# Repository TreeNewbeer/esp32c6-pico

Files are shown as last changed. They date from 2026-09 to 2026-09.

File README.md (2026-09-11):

# ESP32-C6 Pico · Rev A

2026-09-11 第一版 PCB 提交快照：保留用户在居中后对 R19、R15、局部短线及图形的继续调整；R19 / R15 当前坐标为 (115.70, 120.40) / (115.70, 122.36) mm。已重新填铜并同步贴装坐标、二维预览和报告，**ERC 0、DRC 错误 0 / 丝印警告 1、未连接 0、一致性问题 0，QA 39/53**。见 [当前提交记录](output/first-pcb-revision.json)。以下居中对比及旧 3D 图保留为历史记录。

2026-09-10 最新 PCB 微调：以用户已基本完成的第一版 layout 为输入，USB 向右 1.00 mm、两颗按键各向右 0.50 mm，均对齐板框中心 X=110.00 mm；按键间距及纵向位置不变，RST / BOOT 文字跟随移动，D2 位号丝印隐藏。为避让孔位及器件庭院，D4 向右 0.20 mm / 向下 0.10 mm、R15 向右 0.50 mm，局部修整短线；其余器件位置及板框、射频、晶振、禁布区不变。原理图和电路网络未改动，过孔仍为 89 个。重新填铜后 **ERC 0、DRC 错误 0、未连接 0、一致性 0**，保留输入已有的 1 项板头丝印警告；**QA 39/53，无新增失败项**。贴装坐标、二维预览和当前原理图导出的网表已更新，旧 3D 图为历史记录。见 [修改记录](output/usb-buttons-centered.json) 与 [前后对比](output/usb-buttons-centered-comparison.png)；以下先前轮次的数据仅作历史参考。

2026-09-10 最新（仅原理图）：RGB 控制已由 GPIO21 切回 **GPIO8（U1.14，与 J2.7 共用）**，GPIO21（U1.34）标记不连接。已按用户确认对齐官方 DevKitC-1 v1.4：**R9 = 3.3 kΩ 将 GPIO8 上拉到 3.3 V，R19 = 10 kΩ 将二极管阳极侧数据节点上拉到 5 V，R15 = 0 Ω 串联接入 DIN**。保留两颗上拉，D6 阴极朝 GPIO8；R9 / R15 的阻值、BOM 和检查条件均已同步。ERC 0，主控外围实线检查全部通过。PCB、布局和贴装坐标未修改，尚未同步这次 GPIO8 变更；既有 DRC / QA 报告不是新原理图的一致性验证。最新网表、BOM 和两页预览已更新；设计清单同时修正输入原理图已有的 J3 脚序及 D2 封装字段偏差，未改动这些电路。见 [GPIO8 原理图记录](output/rgb-gpio8-schematic.json) 与 [RGB 局部预览](output/schematic/rgb-gpio8.png)。

以下布局轮次和检查数字为历史记录；当前原理图与 PCB 的同步状态以上述说明为准。

当前 PCB 为 **18.0 × 29.0 mm、四层、标称 0.8 mm**，使用 ESP32-C6 QFN40、4 MB 外置 Flash、横向陶瓷天线与原生 USB Serial/JTAG。已按最新原理图移除 USB 的 R12、R13、C27、C28 并完成 USB 直连布线；RGB 灯改用二极管加 5 V 上拉驱动，不再使用电平转换芯片。

2026-09-10 此前 RGB 驱动同步：**按官方 ESP32-C6-DevKitC-1 v1.4 的方式，用 D6（1N4148WS / SOD-323）+ R19（10 kΩ 上拉到 USB 5 V）替换 SN74LV1T125 电平转换器**，删除 U4、其去耦 C26 和 GPIO21 下拉 R16；R15 = 330 Ω 移到 D2 的 DIN 焊盘旁，原来绕过 D2 的数据绕线一并删除。庭院净省约 10 mm²，背面原缓冲器口袋基本腾空，少一个 IC 料号。电平按二极管压降核算（高电平约 3.9 V > 0.7 × VDD，低电平约 0.7 V < 0.3 × VDD，10 kΩ 上拉上升沿约 105 ns），**尚未上电或用示波器实测**。范围、基线对比与哈希见 [RGB 二极管驱动记录](output/rgb-diode-drive.json)，局部对比见 [改动前后对比图](output/rgb-diode-comparison.png)。

2026-09-10 此前 USB 同步：**删除 R12 / R13（22 Ω 串阻）和 C27 / C28（选装电容）**，U1.18 / U1.19 直接连接 USB_D− / USB_D+；保留 USB-C、CC 下拉及 D4 静电保护。清除两条电容支路及其过孔，简化主控附近走线；保持 0.15 mm 线宽、每根数据线两次换层，不增加蛇形补偿。

当前 **59 个器件位、55 个默认装配；ERC 0、原理图一致性 0**。PCB 仍处在重排右排针（J3）的过程中，**DRC 5 项违规、9 项未连接、QA 45/53**：既有的 MCU 7/9 个中心地孔两项检查、匹配网络共轴、天线/晶振间距，加上尚未连上的 7 条 J3 网络、3 个未盖油过孔和 R14 旁一处 +3V3 间距。这些项与 RGB 改动前的同一工程基线（DRC 5、未连接 9、QA 44/52）逐项一致，本轮没有新增违规，但**投板前必须先完成 J3 布线并清零**。除本轮 RGB 三件外，其余器件的位置、角度、安装面和封装不变；BOM、坐标、原理图和 PCB 预览已更新，详见 [RGB 二极管驱动记录](output/rgb-diode-drive.json) 与 [USB 同步记录](output/usb-layout-sync.json)。尚未进行实板 USB、RGB 或射频验证。

以下引脚同步及布局调整记录为历史状态；当前器件数、USB 与 RGB 电路以上面两段为准。

2026-09-10 此前引脚同步：**J2 / J3 全部 24 个脚位已按用户修改的原理图更新，信号、电源和接地均已连通，包括 GPIO5（U1.11 → J2.4）**。左列从板头依次为 GPIO2–GPIO11、3V3、GND；右列为 GPIO1、GPIO0、GPIO15、TX、RX、GPIO18、GPIO19、GPIO20、GPIO22、GPIO23、5V、GND。背面功能丝印、设计清单、原理图预览及 PCB 预览已同步。

**全部 64 个器件的位置、角度、安装面、封装和装配状态均保持输入状态**；板框、logo、禁布区，以及 RF、晶振、USB、Flash 等非排针网络的原有铜线几何保持不变。重排排针支路，同时接回输入板已断开的 C8/C9/C10 3V3 支路，恢复 64 个器件的原理图关联路径。为分隔的表层地铜补充四颗接地过孔，Y1.2 最近地孔距离改善为 0.65 mm；另将一颗原有 VBUS_USB 过孔明确设置为双面盖油。过孔从本次实际输入的 122 颗变为 130 颗。

当前 **ERC 0、DRC 违规 0、未连接 0、原理图一致性 0；独立 QA 48/52**。没有新增失败项；保留四项既有失败：MCU 中心地孔仍为 7/9（两项检查）、天线匹配器件共轴及天线/晶振 8.5 mm 间距目标。最新报告与输入基线见 [引脚同步记录](output/pin-layout-sync.json)；尚未进行实板或射频验证。以下收窄记录属于本轮之前的历史状态，旧脚位和 GPIO5 待连状态以本段及下方接口表为准。

2026-09-10 左侧收窄：板框现为 **18.0 × 29.0 mm**，左板边与 J2 同步右移 **2.00 mm（四个 0.50 mm 步长）**，面积由 580 降至 522 mm²，减少 10%。J2 / J3 中心 X 为 102.25 / 117.75 mm，列中心距 15.50 mm；针距仍为 2.00 mm，焊盘铜到两侧板边仍各 0.575 mm。为避让左排针，仅另调整背面的 C8、C28、R8，其他 60 个器件保持位置、安装面和封装，L2、RF/晶振走线及 USB 数据主干保持不动。J2 第 4 / 5 脚改为 GPIO2 / GPIO1，原理图、设计清单及背面丝印已同步。

历史收窄轮次的待连状态（本轮已完成）：**当时按用户要求保留 GPIO5，U1.11 → J2.8。** U1 焊盘中心为 (106.5625, 115.20) mm，J2 焊盘中心为 (102.25, 128.00) mm；该网络已清除未完成的线头，打开 KiCad 后可直接按飞线补接，信号宽度为 0.15 mm，In1.Cu 继续留作 GND。当前 **ERC 0、DRC 违规 0、原理图一致性 0、未连接 1；QA 45/52**。QA 保留原有六项失败，新增的一项失败就是这条明确预留的连接，未放宽检查。总过孔由 125 减至 124。完成 GPIO5 后须重填铜并重新运行 DRC / QA；当前不是已全部布线的生产文件。范围、备份与端点见 [18 mm 收窄记录](output/width-18mm.json)。

2026-09-09 历史 L2 调整：**L2（2 nH、0402）移至 B.Cu**，从 (102.10, 113.00) mm 移到 (111.55, 112.65) mm，腾出正面左排针旁的原占位。其余 63 个器件、全部信号线、板框、禁布区和两个 logo 均保持输入状态；C11/C19/C20 保持正面。只调整 +3V3 / V3A 的局部连接，移除原输入过孔，新增一颗双面盖油的输出过孔，总数仍为 125。到 U1 两个供电脚的路径约 3.7–3.9 mm（含标称 0.8 mm 过孔贯穿长度）。填铜后 **DRC 0、未连接 0、一致性 0；QA 46/52**，较本次实际输入的 45/51 新增一项通过检查，原有六项失败不变。BOM 器件信息不变，装配坐标和正反面预览已同步；射频与供电表现尚未实测。该轮范围、备份和验证见 [L2 迁移记录](output/l2-back-migration.json)，后文各轮数字保留为历史记录。

2026-09-09 封装替换：**U3 改为 W25Q32JVSNIQ、150 mil SOIC-8（3.9 × 4.9 mm 本体）**；**D5 改为 at820_tiga 的 BAT760-7 / SOD-323**，保持防反灌方向。U3 向左 0.20 mm、向板头 0.10 mm，C6 向右 0.10 mm，D5 中心不动；其余 62 个器件的封装、位置和安装面不变。板框、射频、晶振和 USB 数据线几何保持不变。SOIC 引脚焊盘较长，占位略增；D5 庭院占位约减少 39%，本轮没有缩小板框。

本轮已重新导出网表、ERC、填铜、DRC 和独立 QA：**ERC 0、DRC 0、未连接 0、一致性 0；QA 45/51**，无新增失败项。修改前实际文件重新检查为 43/49，保留 MCU 接地孔数量、匹配网络共轴、天线/晶振间距、晶振接地孔距离、MCU 散热孔清单及一颗普通过孔未显式双面盖油六项既有失败。SOIC-8 没有中心焊盘，工艺目标改为仅 U1 的 9 孔，当前实有 7 孔；没有降低 U1 的要求。具体变更、哈希与基线见 [封装替换记录](output/package-changes.json)。

**F1 已按用户要求删除**：原理图和 PCB 均移除 1206 自恢复保险丝，USB 的 `VBUS_USB` 直接连接 D5 阳极，取消 `VBUS_FUSED` 网络。移除绕到板尾 F1 的走线，保留 D5 防反灌；其余 64 个器件的位置、安装面和封装不变。BOM、装配坐标及预览已同步，默认装配由 59 个减为 58 个。删除后的 ERC、DRC、未连接和原理图一致性均为 0；QA 仍为 45/51，六项既有失败不变。删除 F1 时的检查结果为历史记录，最新结果见上方引脚同步记录。

2026-09-09 历史原理图复核：已对照 `docs/` 的 WROOM-1 / WROOM-1U 模组图，将晶振串联器件 **L4 = 24 nH 更正为 R18 = 0 Ω、0402 电阻**，对应模组图的 R4；原理图符号、PCB 封装、BOM 和检查条件均已同步。另记录 VDDA3P3、VDDA1/VDDA2 的本地去耦差异。重新填铜后，ERC 0 项、原理图一致性 0 项、未连接 0 项；DRC 仍有原有 2 项，独立 QA **43/48 通过**。详细依据与风险见 [外围电路复核](docs/ESP32_C6_SCHEMATIC_REVIEW.md)。下文跳过 QA 的描述属于此前布局轮次。

天线本体在板头右侧横向放置，末端铜箔向左展开、保持开路；板头全层不铺铜区域为 **18.0 × 3.8 mm**。AE1 馈电焊盘与 R6 对齐，正面馈线直接向下连接，不再从匹配网络折返向左。Codex 图标移至左侧；Flash U3、USB TVS D4 和排针位于背面，两颗按键位于正面。

六颗 Flash 串联电阻 R17、R1–R5 已改为 0402，在背面排成一行，中心间距 1.20 mm。Flash U3 与 TVS D4 各向 USB 方向移动 0.80 mm，为焊盘外过孔和这排电阻留出空间；板框不变。C7 在主控 VDD_SPI 扇出旁的正面，C13 位于 3.3V 供电脚附近，保留短去耦连接。RGB 驱动改为二极管电平转换后，D6 占用背面原缓冲器位置，R19、R15 移到 D2 右侧的正面空位，DIN 与数据节点的绕行走线随之删除。排针功能标注统一保留在背面，正面左侧的重复标注已清除。

2026-09-09 历史板宽调整：在天线右移后的 20.5 × 29 mm 版上，将左右板边各收窄 **0.25 mm**，当前板框为 **20 × 29 mm**，面积从 594.5 mm² 降至 **580.0 mm²（减少约 2.44%）**。两列排针位置与 18.10 mm 列间距保持不动，焊盘外缘距两侧板边均为 **0.275 mm**，满足当前 0.25 mm 规则。器件、过孔及走线几何保持输入版本。贴装坐标原点同步更新到新板框左下角 (99.00, 137.50) mm。

2026-09-09 排针内移：板框保持 **20 × 29 mm**，J2 向右、J3 向左各移动 **0.30 mm**，两列中心距由 18.10 mm 改为 **17.50 mm**。J2 / J3 中心 X 分别为 100.25 / 117.75 mm，针距 2.00 mm、脚号与网络顺序不变。焊盘铜外缘距左右侧边各 **0.575 mm**；按封装标称 2.00 mm 宽塑料座计算，本体距侧边各 **0.25 mm**。背面引脚标注及相关局部走线已同步调整，最新预览与装配坐标位于 `output/`。

重新填铜后，**DRC 0 项、未连接 0 项、原理图一致性 0 项**；独立 QA **44/49 通过**，新增的排针边距检查通过，其余五项失败均在修改前存在。旧 `output/qa.json` 的 PCB 哈希与输入文件不符，因此已对原始备份重新建立基线（43/48），未沿用旧报告中的两项孔距违规。当前剩余项为 MCU 接地孔数量、天线匹配器件共轴、天线/晶振间距、晶振接地过孔距离及 11 个散热孔清单。范围与基线对照见 [排针内移检查记录](output/headers-inward.json)。

天线与晶振名义本体边缘最近距离约 **5.070 mm**，低于历史 8.5 mm 项目几何目标；与本次输入 PCB 一致。该历史门槛保持不变，当前独立 QA 据此报告失败。射频和晶振信号仍在正面且不换层，晶振规则区保留；3.8 mm 净空及右侧天线布局尚需实板射频验证。

正面天线旁原 `2.4 GHz` / `NO COPPER` 丝印替换为 **Codex 图标**；背面加入用户个人 logo 的单色人物图形，并将 `REV A` 移到旁边。两个 logo 都是可编辑丝印图形组，背面按正常观看方向镜像放置。原图、SVG、来源和尺寸记录见 [docs/logo/README.md](docs/logo/README.md)。

直接用 KiCad 10 打开 `esp32-c6-pico.kicad_pro`。如编辑器仍显示修改前的内容，请关闭旧窗口并重新打开磁盘文件，避免旧窗口覆盖新文件。

当前封装约定：**射频匹配的 6 个电阻/电容保持 0201，其余全部 35 个电阻/电容统一 0402**，包括 C19、C20、C23 等大容量电源电容及 Flash 串阻。容量、阻值、网络和 DNP 状态保持不变。大容量电源电容保留最低 10V 额定耐压要求，实际料号与偏压下的有效容量仍需核对。变更清单见 [POWER_PASSIVES.md](POWER_PASSIVES.md) 和 [全部阻容封装表](output/passive-packages.csv)。

主原理图已把 ESP32-C6 的供电去耦、上电复位、BOOT、晶振、Flash、USB 直连引出、UART 与 RGB 驱动沿芯片引脚用实线连接。电源输入、USB 接口与排针位于第二页。USB 数据引脚已与第二页的同名数据网络直接连接。

此前尝试了 **18 × 30 mm**：目标尺寸的器件摆放可以容纳，但布线候选仍有 18 处未连接，该轮主工程保留了 20.5 × 32.5 mm，后续从板头收短到 32.0 mm。此前候选、剩余问题和原始检查结果见 [SHRINK_TRIAL.md](SHRINK_TRIAL.md)。

## 已完成的电路

- USB-C 正反插数据连接、CC1/CC2 独立 5.1 kΩ 下拉、USBLC6-2SC6 静电保护；数据线直接连接主控，已删除 22 Ω 串联电阻及选装 EMI 电容。
- AP2112K-3.3 稳压、输入保护、肖特基防反灌、主电源及各供电脚的去耦；RF 电源使用独立 LC 滤波。
- CHIP_EN 的 10 kΩ / 1 µF 上电延时，RESET、BOOT 按键，GPIO8/9 上拉与 UART0 备用下载接口。
- W25Q32JVSNIQ、SOIC-8 150 mil 外置 Flash，真正接通 VDD_SPI；40 MHz / 8 pF 晶振，两个外壳脚接地，并保留负载调试与 R18 = 0 Ω 串联电阻。
- 芯片端 CLCCL 射频网络、天线端 π 网络、低电容 ESD 选装位，以及陶瓷天线开路端调谐铜箔。
- WS2812B-2020 RGB 灯：原理图改由 GPIO8 经 D6（1N4148WS）与 R19（10 kΩ 上拉到 USB 5 V）驱动，R9 = 3.3 kΩ 保留 GPIO8 的 3.3 V 上拉，R15 = 0 Ω 接入 DIN，控制引脚和三个电阻值已按官方 v1.4 对齐；PCB 待用户同步。

## 检查与交付文件

当前原理图 ERC 0、实线检查通过，见 `output/rgb-gpio8-schematic.json`。PCB 尚未同步本次 GPIO8 变更；`output/drc-final.json` 和 `output/qa.json` 保留此前布局结果，下文各日期记录保留当时状态。

2026-09-09 历史排针内移轮次使用 KiCad 10.0.6 重新填铜并检查：**DRC 0 项、未连接 0 项、原理图一致性 0 项；独立 QA 44/49 通过，无新增失败项**。本轮未修改原理图，既有 ERC 报告为 0 项。当前报告为 `output/drc-final.json`、`output/qa.json` 和 `output/headers-inward.json`；`output/layout-20x29mm.json` 及此前两项孔距违规的记录属于历史轮次。

原先 65 项一致性报错来自 PCB 器件字段缺失。现已按原理图为 65 个器件同步 141 处字段，包括 MPN、AssemblyNote 和 Datasheet；新增字段隐藏显示，保留封装库自带的额外字段。原理图、网络连接、封装、器件值和 DNP 状态保持不变。已重新填铜，并在重新加载磁盘 PCB 后启用 `--schematic-parity` 验证为 0 项；QA 新增逐字段比较与一致性报告检查，后续 DRC 命令也必须带此参数。

USB 保持简洁路径，没有加入蛇形等长补偿。两根线在按键上方换到底层，经过靠近连接器的 TVS，再换回正面连接 USB-C 焊盘。接受自然扇出带来的少量长度差；QA 长度统计区分铜层，并计入标称过孔贯穿长度。

全板信号走线统一为 **0.15 mm**（含 USB、射频、晶振及芯片扇出），非 GND 电源走线统一为 **0.20 mm**；GND 保留原有线宽。`Power` 网络类覆盖 `+3V3`、`+5V`、`V3A`、`VBUS_USB`、`VDD_SPI`，其他信号使用 `Default`。自定义规则同时限制最小和最大线宽，独立 QA 核对每段走线与实际网络类；相关局部路径已按新宽度调整。线宽统一不代表阻抗或载流能力已经实测达标。

外围焊盘内的过孔已改为焊盘外短线扇出，并检查正反面的阻焊开窗；孔边间距至少 0.10 mm。当前仅允许 U1 中心接地焊盘的 9 个填孔盖铜过孔，实际清单为 7 个；SOIC-8 U3 无中心焊盘。为腾出局部扇出空间，调整了 C7、C11、R2、R3、R7 的位置；同批调整的 C27、R16 已在后续 USB 与 RGB 简化中删除。

| 文件 | 用途 |
| --- | --- |
| `esp32-c6-pico.kicad_sch` / `power-io.kicad_sch` | 两张可编辑原理图 |
| `esp32-c6-pico.kicad_pcb` | 已布线 PCB，含叠层和禁布区 |
| `esp32-c6-pico.kicad_dru` | 固定线宽、焊盘孔距与晶振下方的非接地过孔禁布规则 |
| `output/pcb-front.svg` / `pcb-back.svg` | 正反面布线预览 |
| `output/rgb-diode-drive.json` | RGB 二极管电平转换的改动范围、基线对比与验证 |
| `output/rgb-diode-comparison.png` / `.svg` | RGB 驱动改动前后的正反面局部对比 |
| `output/pin-layout-sync.json` | 最新排针引脚、完整布线、位置保护、输入基线及验证 |
| `output/width-18mm.json` | 历史 18 mm 收窄、当时 GPIO 换序与待连线记录 |
| `output/l2-back-migration.json` | L2 背面迁移范围、备份、连通性及检查基线 |
| `output/package-changes.json` | 历史封装替换范围、尺寸、网表与检查基线 |
| `output/headers-inward.json` | 历史排针内移的尺寸、修改范围及检查基线 |
| `output/width-20mm-comparison.png` / `.svg` | 历史 20.5 → 20.0 mm 板宽对比 |
| `output/antenna-right-29mm-comparison.png` / `.svg` | 历史 28 → 29 mm 与天线右移对比 |
| `output/antenna-28mm-comparison.png` / `.svg` | 历史 32 → 28 mm 压缩对比 |
| `output/antenna-layout-comparison.png` / `.svg` | 此前天线末端铜箔调整的历史对比 |
| `output/usb-routing-comparison.png` / `.svg` | 此前删除 USB 蛇形的历史局部对比 |
| `output/layout-repack-comparison.png` / `.svg` | 此前换面布局及缩短板框的历史对比 |
| `output/crystal-isolation-comparison.png` / `.svg` | 此前天线前移并加长板框的历史对比 |
| `output/crystal-down-headers-comparison.png` / `.svg` | 此前晶振下移、排针换面与尺寸调整对比 |
| `output/board-3d-top.png` / `board-3d-bottom.png` | 含最新 logo 的正反面 3D 布局预览 |
| `docs/logo/` | 个人原图、两面丝印 SVG、图形来源和放置参数 |
| `output/assembly-front.svg` / `assembly-back.svg` | 带位号的装配视图 |
| `POWER_PASSIVES.md` / `output/power-passives.csv` | 当前 0402 约定、封装变更记录和选料说明 |
| `output/passive-packages.csv` | 全部 40 个电阻/电容及累计 12 个封装变化记录 |
| `output/bom.csv` | BOM；`Populate=NO` 表示不装 |
| `output/placement.csv` | 双面贴装坐标，已排除 DNP；坐标原点为板左下角 |
| `output/via-in-pad.csv` | 当前 7 个 MCU 散热焊盘内孔，尚未满足 9 孔目标；须填孔盖铜 |
| `FABRICATION.md` | 必须确认的工艺、阻抗与样板验证项目 |

板上共 59 个器件位，默认装配 55 个。默认不装 D1、L3、C17、C18。3D 图为布局示意，部分标准库封装缺少 3D 模型；器件是否装配以 BOM 和二维装配图为准。

## 接口与下载

**从正面看**，USB 朝下、天线朝上时，J2 在左、J3 在右，两列 1 脚均靠近天线；从背面观察时左右对调，编号不倒序。排针塑料座和长针在背面，正面为焊接端。针距为 **2.00 mm**，两列中心距为 **15.50 mm**；这些尺寸不能按 2.54 mm 面包板间距处理。

| 脚号 | J2（左列） | J3（右列） |
| --- | --- | --- |
| 1 | GPIO2 | GPIO1 |
| 2 | GPIO3 | GPIO0 |
| 3 | GPIO4 | GPIO15 |
| 4 | GPIO5 | UART0 TX / GPIO16 |
| 5 | GPIO6 | UART0 RX / GPIO17 |
| 6 | GPIO7 | GPIO18 |
| 7 | GPIO8 | GPIO19 |
| 8 | GPIO9 / BOOT | GPIO20 |
| 9 | GPIO10 | GPIO22 |
| 10 | GPIO11 | GPIO23 |
| 11 | 3V3 输出 | 5V 输出* |
| 12 | GND | GND |

*5V 引脚实际电压等于 USB 电压扣除 D5 压降，不是精密 5.00 V。USB 电源直接经 D5 给稳压器和 5V 引脚供电，板上不再设置自恢复保险丝；RGB 灯与其 10 kΩ 上拉接 USB 原始电源。3V3/5V 引脚按电源输出使用，不要在连接 USB 时再向这些引脚注入外部电源。所有 GPIO 为 3.3 V 逻辑。

USB 下载使用芯片内置 USB Serial/JTAG（GPIO12=D-，GPIO13=D+）。需要手动进入下载模式时：按住 BOOT，点按 RESET，再松开 BOOT。UART0 备用下载时，使用 3.3 V 电平的串口适配器，交叉连接 TX/RX 并共地。GPIO4、5、8、9、15 是启动配置脚，外接电路不能在复位时强制成错误电平。

## 设计边界

这是一版用于验证的样板设计，尚未进行上电、测温或射频实测。横向天线、轴向开路端铜箔、18.0 × 3.8 mm 净空和缩短后的地平面均属于本工程的样板选择；3.8 mm 不是厂商保证的最小净空，原参考板的增益、带宽和方向图不能直接套用。匹配、效率和通信表现需在实际板卡及外壳中验证。

射频匹配、晶振负载与名义阻抗均需结合实际叠层、装配和外壳确认。U1 的中心散热焊盘内孔须填孔盖铜，当前 7 孔尚未满足 9 孔目标，普通盖油不能替代；具体工艺与实板验证要求见 `FABRICATION.md`。

`tools/` 保留了设计过程与验证脚本。`verify_design.py` 可重跑网络与规则核对；布局生成和布线脚本会重建或修改 PCB，不能当成对最终布线无损的更新命令。

## 依据

- [Espressif ESP32-C6 原理图设计指南](https://docs.espressif.com/projects/esp-hardware-design-guidelines/zh_CN/latest/esp32c6/schematic-checklist.html)：供电、启动配置、晶振、USB 与射频匹配。
- [Espressif ESP32-C6 PCB 布局指南](https://docs.espressif.com/projects/esp-hardware-design-guidelines/zh_CN/latest/esp32c6/pcb-layout-design.html)：接地参考层、芯片底部接地、射频与时钟路径。
- 工程内 `docs/C127611_CAA3DCCF3A021118096CAD99FC50242A.pdf`，Walsin `ASC_RFANT5220110A0T_V13` 第 3–4 页：天线焊盘、开路端铜箔与测试板几何。
- [Eaton E9X 数据手册](https://www.eaton.com/content/dam/eaton/products/electronic-components/resources/data-sheet/eaton-e9x-crystal-resonator-mhz-data-sheet-elx1389-en.pdf)：Y1 的频率、负载、电气规格与引脚。
- [Diodes 1N4148WS 数据手册](https://www.diodes.com/assets/Datasheets/1N4148WS_BAV16WS.pdf)：RGB 数据电平转换二极管，SOD-323、VF ≤ 0.715 V @ 1 mA、CT ≤ 2 pF。
- 工程内 `docs/esp32-c6-devkitc-1-schematics_v1.4.pdf` 第 2 页：官方 RGB 驱动使用 D11（1N4148W）+ R29（10 kΩ 上拉到 VCC_5V）+ R17（0 Ω），本板据此改用同一结构。
- [Nexperia PESD5V0F1BL-Q 数据手册](https://assets.nexperia.com/documents/data-sheet/PESD5V0F1BL-Q.pdf)：低电容天线 ESD 选装器件。

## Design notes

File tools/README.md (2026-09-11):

# 设计过程脚本

2026-09-10 最新（仅原理图）：RGB 控制改为 GPIO8 / U1.14，与 J2.7 共用；U1.34 / GPIO21 标记不连接。实线检查与 RGB 拓扑检查同步到 GPIO8，重画模板也替换已删除的 U4 / C26 / R16 逻辑，保留二极管两侧的 R9 / R19。已按用户确认将 R9 改为 3.3 kΩ、R15 改为 0 Ω，R19 保持 10 kΩ；RGB 拓扑检查同时要求这三个官方阻值、R9 接 +3V3、J2.7 共用 GPIO8 及 GPIO21 已空置。新网表 ERC 0、实线检查全部通过；PCB 未改动，本轮未运行 PCB DRC / QA，旧报告不能作为新网表的一致性结论。设计清单和 BOM 按实际输入原理图修正已有的 J3 脚序、D2 封装字段偏差；没有重画或更改这些电路。见 [GPIO8 原理图记录](../output/rgb-gpio8-schematic.json)。

最终可编辑工程是上一级目录中的 KiCad 文件；`output/` 仅保留最终交付和检查结果。

`verify_design.py` 是核对入口：读取原理图导出的 `output/netlist.xml`、最终 PCB、ERC/DRC 报告，核对逐焊盘网络、封装、接地参考层、关键走线层和 USB 长度，并更新 QA/焊盘内孔清单。板框和天线净空尺寸从 PCB 几何读取，当前检查横放天线、18.0 × 29.0 mm 板框、18.0 × 3.8 mm 全层净空及末端铜箔的几何连续性。同时检查 Flash / TVS 在背面、两颗按键在正面，以及 USB 的换层数量和跨层路径连通性。晶振隔离检查还核对 8.5 mm 的项目本体间距目标、2.4 mm 的时钟引脚间距、各接地焊盘 1 mm 内的接地过孔，以及第二层填铜对晶振参考区和本体投影的完整覆盖。另检查排针在背面、编号从板头向下排列、2.00 mm 针距和 15.50 mm 列中心距，并核对排针标称 2.00 mm 宽塑料座及焊盘铜外缘距侧边分别至少 0.25 mm、0.575 mm。另核对两个 logo 图形组仅位于正确丝印层、旧天线文字已替换、图形距板边至少 0.25 mm。它不修改 PCB，也不验证射频性能。

2026-09-10 RGB 二极管驱动：按用户要求改用官方 ESP32-C6-DevKitC-1 v1.4 的驱动方式，删除 U4（SN74LV1T125）、去耦 C26 与下拉 R16，新增 D6（1N4148WS / SOD-323，阴极接 GPIO21）和 R19（10 kΩ 上拉到 VBUS_USB），R15 = 330 Ω 移到 D2 右侧并删除原来绕过 D2 的数据绕线。`verify_design.py` 新增一项 RGB 拓扑检查，封装数量核对改为 40 个 R/C，`component_sides` 记录 D6 / R19 / R15；`verify_schematic_wiring.py` 的实线清单同步为 D6、R19、R15。当前 **ERC 0、原理图一致性 0、DRC 5 项违规、9 项未连接、QA 45/53**；同一工程改动前（仅重新填铜）的基线为 DRC 5、未连接 9、QA 44/52，两者逐项一致，剩余项全部来自尚未完成的右排针（J3）布线，不是本次改动引入。详见 [RGB 二极管驱动记录](../output/rgb-diode-drive.json)。

2026-09-10 最新 USB 同步：删除 R12、R13、C27、C28，60 个器件位、56 个默认装配，**ERC / DRC / 未连接 / 一致性均为 0，QA 48/52**。四项既有失败不变。USB 路径检查直接核对 U1.18 / U1.19 到 USB-C 正反插数据焊盘的连接、旧器件和网络已移除；长度不再计入串阻焊盘间距。主页面实线检查追踪主控引脚到 USB 跨页标签的线段。`redraw_schematic.py` 的 USB 模板已同步为直连，本轮没有执行重画。详见 [USB 同步记录](../output/usb-layout-sync.json)。

2026-09-10 此前引脚同步：两列全部 24 个脚位按新原理图更新，GPIO5 已接到 J2.4；全部 64 个器件位置、角度与安装面不变。当前 **ERC 0、DRC 违规 0、一致性 0、未连接 0；QA 48/52**。保留四项既有失败（MCU 7/9 地孔的两项检查、匹配网络共轴、天线/晶振间距），没有新增失败项；晶振地孔距离和普通过孔显式双面盖油检查现已通过。网表、设计清单、器件原理图路径和预览已同步。详见 [引脚同步记录](../output/pin-layout-sync.json)。

2026-09-10 历史收窄为 18 × 29 mm，J2 第 4 / 5 脚改为 GPIO2 / GPIO1。用户授权保留 GPIO5（U1.11 → J2.8）供手动布线，当前 **ERC 0、DRC 违规 0、一致性 0、未连接 1；QA 45/52**。原有六项失败不变，额外失败为这一条待连线；`KiCad PCB has no unconnected items` 检查保持严格，不将授权的未完成连接当作通过。详见 [18 mm 记录](../output/width-18mm.json)。

`--board` 和 `--output-dir` 可用于隔离候选板的核对；对应目录需提供原理图网表及 ERC / DRC 报告。

2026-09-09 L2 迁移后，QA 增加背面安装、C11 保持正面及 V3A 到 U1.2/U1.3/C11/C19/C20 的跨层连通性检查。`rf_supply_filter` 记录输出路径和换层数量；长度按铜线中心线加标称过孔贯穿长度估算，不代表寄生参数或射频性能验证。本轮输入重新检查为 45/51，迁移后为 46/52，六项既有失败不变；DRC、未连接和原理图一致性均为 0。范围与备份见 [L2 迁移记录](../output/l2-back-migration.json)。

器件字段核对逐项比较 PCB 与网表中的 Value、MPN、AssemblyNote、Datasheet 等原理图实例字段，包括空值；封装库自带的额外字段保留。DRC 必须启用 `--schematic-parity`，其结果也纳入 QA。仅检查走线的 DRC 报告不能代替原理图一致性检查。

封装核对覆盖当前全部 40 个电阻、电容：射频匹配的 C2、C3、C16、C17、C18、R6 为 0201，其余 34 个为 0402。晶振串联器件按模组图由原 L4 更正为 R18 = 0 Ω；QA 同时核对其电阻符号、数值、装配状态及 U1.39 / Y1.1 / C4.1 的连接。定义与变更记录见 [POWER_PASSIVES.md](../POWER_PASSIVES.md)。

线宽核对覆盖全部走线和圆弧：信号固定 0.15 mm，非 GND 电源固定 0.20 mm，同时检查实际网络类及默认布线宽度。电源网络集合维护在 `build_pcb.py` 的 `POWER_NETS`，项目 `Power` 类与 `.kicad_dru` 应同步；GND 不参与固定线宽检查。QA 的 `track_width_policy` 保存各网络实际线宽和线段数量。

核对还包括正反面 SMD 阻焊开窗到孔边的 0.10 mm 间距，涵盖同网络及 DNP 焊盘；仅按固定位置允许 U1 的 9 个中心接地孔；SOIC-8 U3 无中心焊盘。工程的 `.kicad_dru` 使用 `physical_hole_clearance` 补上同网络孔距检查，独立 QA 再核对阻焊扩展与这 9 个 MCU 工艺例外。规则语义见 [KiCad 10 自定义规则文档](https://docs.kicad.org/10.0/en/pcbnew/pcbnew.html#custom-design-rules)。

其他脚本保留布局生成、扇出、局部布线和视图生成过程，部分会重建或修改 PCB。设计中间文件已归档到本地 `tmp/routing-history/`，不纳入 Git 仓库；历史脚本里的中间文件路径不代表可直接执行的一键重建流程。修改最终工程请优先使用 KiCad，并先备份。

`tune_usb.py` 已停用，执行时仅提示退出。当前 USB Full-Speed 主干采用短而平行的直线，不为几毫米的长度差添加蛇形补偿。

`add_vippo.py` 同样已停用，避免再次将过孔插入外围 QFN 焊盘。历史布局/布线脚本不能无损重建当前的局部扇出；使用它们生成候选板后仍需完整运行 DRC 和独立 QA。

本机验证命令（Debian，KiCad Flatpak；在仓库根目录执行）：

```sh
flatpak run --command=kicad-cli org.kicad.KiCad pcb drc --schematic-parity --format json --exit-code-violations -o output/drc-final.json esp32-c6-pico.kicad_pcb
flatpak run --command=python3 org.kicad.KiCad tools/verify_design.py
```

Windows 验证示例（PowerShell）：

```powershell
& 'C:\Program Files\KiCad\10.0\bin\kicad-cli.exe' sch export netlist --format kicadxml -o output/netlist.xml esp32-c6-pico.kicad_sch
& 'C:\Program Files\KiCad\10.0\bin\kicad-cli.exe' sch erc --format json --exit-code-violations -o output/erc.json esp32-c6-pico.kicad_sch
& 'C:\Program Files\KiCad\10.0\bin\kicad-cli.exe' pcb drc --schematic-parity --format json --exit-code-violations -o output/drc-final.json esp32-c6-pico.kicad_pcb
& 'C:\Program Files\KiCad\10.0\bin\python.exe' tools\verify_design.py
```

`redraw_schematic.py` 从当前设计清单和内嵌符号重画两页原理图，不生成 PCB。使用前备份，之后重新导出网表、ERC 并同步 PCB 符号路径。它使用仓库内两份标准电源符号，来源见 `libs/README.md`。原 `build_schematic.py` 历史生成入口已停用。

`verify_schematic_wiring.py` 独立读取主原理图的实线与引脚位置，不把标签或电源别名当作连线，核对 U1 的关键外围可以沿线追踪。该检查与原理图/PCB 符号路径核对均已纳入 `verify_design.py`。

2026-09-09 的 29 mm 布局迭代曾跳过独立 QA。此后的晶振串联电阻修正已重新运行 QA，该次检查为 43/48 通过，保留五项已有失败条件。历史 8.5 mm 天线/晶振目标仍保留，该轮约 5.100 mm；不得将该版描述为 QA 全部通过。详情见 [外围电路复核](../docs/ESP32_C6_SCHEMATIC_REVIEW.md)。

2026-09-09 排针内移后，列中心距检查改为 17.50 mm，并新增塑料座与焊盘距侧边的检查。当前 `output/qa.json` 为 **44/49 通过**，DRC、未连接和原理图一致性均为 0。由于旧报告的 PCB 哈希与输入文件不符，已重新检查修改前备份：43/48，五项失败条件与当前相同。当前既有失败项是 MCU 接地孔数量、天线匹配器件共轴、天线/晶振间距、晶振接地过孔距离和 11 个散热孔清单；不可沿用历史报告中的两项孔距违规。详细范围及备份路径见 [排针内移记录](../output/headers-inward.json)。

2026-09-09 Flash / 二极管封装替换：当前 QA **45/51**，重新建立的输入基线为 43/49；保留六项既有失败（含一颗普通过孔未显式双面盖油）。新增 SOIC-8 的八引脚/无 EPAD 核对及 BAT760-7 封装与极性核对；U1 九孔要求保持，当前实有七孔。ERC、DRC、未连接及原理图一致性均为 0。`redraw_schematic.py` 已移除 U3.9 的生成逻辑；修改该脚本没有重建最终原理图或 PCB。随后按用户要求删除 F1，USB 电源直接接 D5 阳极，移除 `VBUS_FUSED` 的网表和网络类配置；64 个器件位、58 个默认装配，QA 仍为 45/51。核对包含 F1 确实删除和 D5 的 USB 输入连接。当前证据见 [封装替换记录](../output/package-changes.json)。

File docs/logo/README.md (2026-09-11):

# PCB 丝印图形

2026-09-08：正面以 Codex 图标替换天线旁的 `2.4 GHz` 和 `NO COPPER`；背面加入用户提供的个人 logo。图形以可编辑的 KiCad 图形组保存在 PCB 中，不作为电气器件加入 BOM。

| 图形 | 来源 / 文件 | PCB 图形组 | 丝印层 | SVG 画布尺寸 |
| --- | --- | --- | --- | --- |
| Codex | [单色 SVG](codex-silkscreen.svg) | `LOGO_CODEX` | F.SilkS | 2.8 × 2.8 mm |
| 个人 logo | [原始 JPG](logo.jpg)、[丝印 SVG](personal-silkscreen.svg) | `LOGO_KZL` | B.SilkS | 约 6.43 × 8.20 mm |

Codex 图标采用 [LobeHub 图标仓库的 Codex 单色矢量文件](https://github.com/lobehub/lobe-icons/blob/master/packages/static-svg/icons/codex.svg)，属于社区整理的 OpenAI Codex 标识，并非本项目自创商标。图形来源及 SHA-256、放置坐标、尺寸记录在 [layout.json](layout.json)。

个人图形依据 `logo.jpg` 的中央人物描摹为单色轮廓，省去背景建筑、飞船等细节，保留头部、眼睛、胸前 K 标记与服装形状。主要轮廓约 0.12 mm；K 以实心徽章中的留白呈现。原始 JPG 保留不变，SVG 为便于丝印而整理的版本。

SVG 按正常观看方向保存。背面图形在 PCB 坐标中镜像，从板背面看时方向正确。`REV A` 移到图形旁边；两面的 logo 均只使用丝印层。删除 `NO COPPER` 文字后，天线铜层禁布区仍由 PCB 规则区和工程说明定义。

KiCad 中可按上述名称选中图形组，统一移动或缩放；修改尺寸后需检查丝印细节、焊盘间距与板边余量。当前 PCB、装配资料和 3D 预览以仓库根目录的工程及 `output/` 为准。历史布局生成脚本不包含最终图形组，不能无损重建当前板卡。

2026-09-09：随 28 mm 板框移动并缩放 PCB 内的原生图形。Codex 源 SVG 保持 2.8 × 2.8 mm，PCB 按 75% 缩放至 2.1 × 2.1 mm，中心 (115.3, 110.9)；个人 logo 按 55% 缩放至约 3.54 × 4.51 mm，中心 (109, 111.95)，背面镜像与原丝印线宽保留。当前 PCB 放置比例见 `layout.json`。

随后调整为 29 mm 板长：Codex 图标移至正面左侧，中心改为 (102.60, 110.00) mm；缩放比例、线宽和背面个人图形保持上一版。

随后板宽由 20.5 mm 收窄到 20.0 mm（两侧各 0.25 mm），两个 logo 的坐标、尺寸与图形均保持不动。

提交前保留编辑器中的最新调整：背面 `LOGO_KZL` 整组平移 (+0.012374, −0.858847) mm，画布中心更新为 (109.012374, 111.091153) mm；尺寸、线宽与背面镜像保持不变。正面 logo 位置不变，当前坐标已同步至 `layout.json`。

2026-09-10：板宽由 20 mm 缩至 18 mm，仅左板边向右内收 2 mm；两个 logo 的位置、尺寸、图形和图层保持不变。板框尺寸已同步至 `layout.json`。

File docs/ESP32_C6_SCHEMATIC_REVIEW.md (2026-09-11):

# ESP32-C6 外围电路复核（2026-09-09）

本次复核根目录两页原理图及现有 PCB，优先逐图核对本地 WROOM-1 / WROOM-1U 模组原理图，再交叉检查乐鑫裸芯片指南、芯片管脚表和 DevKitC-1。**未发现 U1 管脚接错、Flash 信号互换、USB 极性接反或 EN/BOOT 连接错误；发现晶振串联器件的官方资料差异，以及两组电源去耦与参考图不一致。**连接正确不代表模拟参数、启动裕量和射频性能已经验证。

按用户指定的模组参考，已将原 L4 = 24 nH 更正为 **R18 = 0 Ω、0402 电阻**，同步原理图符号、PCB 封装、设计清单、BOM、贴装坐标、预览与 QA。原 R4 已用于 Flash，因此新位号采用 R18。其余外围的核对结果与待验证项如下。

## 1. 原 L4 更正为 R18 = 0 Ω，对应模组图 R4

| 依据 | 晶振串联器件 | 说明 |
| --- | --- | --- |
| [本地模组手册 v1.4](esp32-c6-wroom-1_wroom-1u_datasheet_cn.pdf)，PDF 第 37 页图 8-1、第 38 页图 8-2 | **R4 = 0 Ω，电阻符号** | 两张图都注明其数值随实际 PCB 调整。不能把这张图里的 R4 读成 24 nH 电感。 |
| [乐鑫 QFN40 核心电路原图](https://docs.espressif.com/projects/esp-hardware-design-guidelines/zh_CN/latest/esp32c6/_images/esp32c6-sche-core-qfn40.png)，2026-09-09 获取 | **L4，电感符号，初始建议 24 nH** | 图中另有电阻符号，两者能够直接区分。 |
| [乐鑫晶振设计说明](https://docs.espressif.com/projects/esp-hardware-design-guidelines/zh_CN/latest/esp32c6/schematic-checklist.html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)，同日获取 | XTAL_P 串联电感，初始 24 nH | 正文将其列为启动所需器件，同时要求最终值经过测试确认。 |
| [本工程原理图](../esp32-c6-pico.kicad_sch) / [BOM](../output/bom.csv) | **R18 = 0 Ω，0402 电阻** | U1.39 → R18.1；R18.2 → Y1.1、C4.1；U1.38 → Y1.3、C5.1。对应本次指定的模组方案。 |

最新截图 `~/Pictures/agents/2026-09-09_10-45.png` 的绿框与模组手册第 37 页一致：该器件明确标为 R4、0 Ω。**本次以这份模组图为基准，采用电阻符号与 0 Ω 装料。**上表另列裸芯片指南的 24 nH 方案，只记录两份资料的差异，不将其作为本工程当前装料。两份资料未解释差异原因，实际晶振启动、频偏和射频表现仍需样板验证。

Y1 的两个接地脚 2、4 均接 GND；C4、C5 均为 12 pF，分别位于晶振两端。工程选择 CL = 8 pF，12 pF / 12 pF 配对的串联等效为 6 pF，另加约 2 pF 寄生只是初估，不能当作频偏验证。模组图将负载电容标为 TBD，没有提供可直接抄用的定值。

## 2. 电源去耦存在需要核实的差异

以下两项均可在上述模组手册第 37、38 页和裸芯片核心原图中直接看到。

| 网络 / 本工程位号 | 官方参考 | 本工程现状 | 评估与后续处理 |
| --- | --- | --- | --- |
| VDDA3P3：U1.2、U1.3；L2、C11、C19、C20 | 2.0 nH 滤波电感后有本地 **100 nF**，电感前另有储能及旁路电容 | L2 = 2.0 nH；电感后 V3A 上为 C11 = 1 µF、C19/C20 各 10 µF，**没有 100 nF** | 属于明确的参考差异与高频去耦风险。建议在芯片侧补 100 nF；也可评估将 C11 改为 100 nF，利用 C19/C20 保留储能，但必须同时检查位置、回流与实际阻抗。不能因标称容量更大就认定等效。 |
| VDDA1 / VDDA2：U1.37、U1.40；C14、C15 | 两脚接 3.3 V，并配 **1 µF + 10 nF** 的本地组合 | C14、C15 各 100 nF；主电源网上另有 C9 = 1 µF，但并非上述本地组合 | 建议复核晶振侧供电去耦，按参考组合评估 C14/C15 的数值与位置。共享同一网络只证明直流连接，不能证明高频去耦等效。 |
| VDD_SPI：U1.23；C7、C6、U3.8 | 1 µF + 100 nF，为外置 Flash 供电 | C7 = 1 µF、C6 = 100 nF 均在 VDD_SPI；U3.8 已接通 | 数值和网络对应；C7 在 U1 旁、C6 在 Flash 旁。不能把全网的两颗电容都描述成位于 U1 引脚处。 |
| 数字供电：U1.5、U1.28 | 各配置 100 nF 去耦 | C12、C13 各 100 nF 接 +3V3 | 原理图对应；C12 的 PCB 孔距问题另列于第 4 节。 |

前两项是本次新列出的设计风险，尚无证据证明已经引起故障，因此没有直接改料。后续修订应先确定参考去耦方案，再同步原理图、BOM 与 PCB，并验证供电纹波和晶振启动。

此外，大容量 0402 电容仍缺少已落实的完整料号与偏压曲线，详见 [POWER_PASSIVES.md](../POWER_PASSIVES.md)。本次未完成采购选型。L2 的 BOM 仅用通用参数占位，其额定电流、直流电阻及高频特性也未按具体器件闭环。[AP2112 官方资料](https://www.diodes.com/part/view/AP2112?BackID=9304)给出 600 mA 额定输出能力和 1 µF 稳定性条件；板上的热条件、外部负载及实际有效电容量仍需单独验证。

## 3. 其余外围逐项结果

管脚编号以 [ESP32-C6 芯片手册](https://www.espressif.com/sites/default/files/documentation/esp32-c6_datasheet_cn.pdf) v1.5 第 16–17、29、31–33 页和本地模组图为依据。检查的是 **QFN40 裸芯片管脚**；模组的 29 个焊盘编号、QFN32 芯片编号不能代入本工程。

2026-09-10 更新：下表的 USB、UART、RGB 三行已按当日改动（删除 USB 串阻与选装电容、排针脚位调整、RGB 改用二极管电平转换）改写为当前工程状态，可对照 [USB 同步记录](../output/usb-layout-sync.json) 与 [RGB 二极管驱动记录](../output/rgb-diode-drive.json)；第 4、5 节仍是 2026-09-09 当次的检查结果与证据，没有回填。

| 项目 | 本工程连接 / 取值 | 结果 |
| --- | --- | --- |
| 电源与地 | 2/3 → V3A；5/28/37/40 → +3V3；23 → VDD_SPI；41 → GND | 连接对应；去耦差异见上表。 |
| EN / RESET | U1.4；R7 = 10 kΩ 上拉；C21 = 1 µF 对地；SW1 下拉复位 | 对应模组手册第 39 页说明及 DevKitC-1 的 RC；实际时序尚未测量。 |
| BOOT | U1.15 = GPIO9，R8 = 10 kΩ 上拉、SW2 对地；U1.14 = GPIO8，R9 = 10 kΩ 上拉 | 可形成 GPIO8 = 1、GPIO9 = 0 的下载组合；板上没有给 GPIO9 装大电容。 |
| 其他 strapping 管脚 | GPIO4/5/15 引至排针 | 未被板载负载强制；外接电路仍会影响复位采样。 |
| 32.768 kHz RTC | U1.6/7 作为 GPIO0/1 引出 | 外部 RTC 晶振可选；未装不是遗漏必需元件。 |
| USB | U1.18 / GPIO12 → USB_D−、U1.19 / GPIO13 → USB_D+，直接接 J1 的 A7/B7、A6/B6 与 D4 的两路 TVS；2026-09-10 已按用户原理图删除 R12/R13 = 22 Ω 串阻及选装的 C27/C28 | 极性、两种插入方向及 TVS 网络对应；CC1/CC2 各有独立 5.1 kΩ 下拉。全速数据不再经串阻，改为短而平行的直连走线，阻抗仍未实测。 |
| UART | U1.29 → R14 = 499 Ω → U0TXD → J3.4；U1.30 → U0RXD → J3.5 | 与模组图 TX 阻尼电阻及芯片 UART0 功能对应；脚位按 2026-09-10 的排针顺序，旧表记的 J3.6 / J3.7 是调整前的编号。 |
| RGB | U1.34 / GPIO21 → D6（1N4148WS，阴极朝 MCU）→ 数据节点（R19 = 10 kΩ 上拉到 VBUS_USB）→ R15 = 330 Ω → D2.DIN | 结构与 DevKitC-1 v1.4 的 D11 / R29 / R17 相同，仅串联电阻取 330 Ω；驱动脚仍为本工程分配的 GPIO21，未占用 GPIO8 启动上拉节点。 |
| 射频 | U1.1 → L1 → C16 → R6 → AE1；C3/C2 分别为芯片侧和中间对地支路；L3/C17/C18/D1 不装 | 器件类型与网络对应现行参考的可调结构；本地模组使用的简化匹配网络并非本板唯一可用方案。 |
| 天线开路端 | AE1.2 不接地 | 本工程是 RFANT5220110A0T，不能把模组 PCB 天线图上的地端复制到陶瓷天线开路端。 |

Flash 六路逐条对应如下；[Winbond W25Q32JV 官方资料](https://www.winbond.com/resource-files/W25Q32JV%20RevJ%2012242024%20Plus.pdf) Rev J 的 WSON 管脚定义与模组图一致。

| ESP32-C6 管脚 | 功能 | 本工程串阻 | U3 管脚 |
| --- | --- | --- | --- |
| 20 | SPICS0 | R17，0 Ω | 1，/CS |
| 21 | SPIQ | R1，0 Ω | 2，DO / IO1 |
| 22 | SPIWP | R2，0 Ω | 3，/WP / IO2 |
| 24 | SPIHD | R3，0 Ω | 7，/HOLD / IO3 |
| 25 | SPICLK | R4，0 Ω | 6，CLK |
| 26 | SPID | R5，0 Ω | 5，DI / IO0 |

U3.8 接 U1.23 的 VDD_SPI，未误接地或悬空。模组 Flash /CS 上的 10 kΩ 标为不装，本工程未装这颗电阻不能直接判错。模组在 GPIO19 上预留的 R17 = 0 Ω 与本工程 Flash /CS 串阻 R17 不是同一功能，比较时不能按位号直接配对。

本地 [DevKitC-1 v1.4 原理图](esp32-c6-devkitc-1-schematics_v1.4.pdf)第 2 页用于核对 EN、BOOT、GPIO8 上拉、USB-C 和外部接口；其主控是完整模组，没有展开内部晶振和 Flash，不能单独作为本板裸芯片外围的依据。CP2102N、双 USB 接口、自动下载晶体管和 GPIO8 驱动 RGB 是开发板自身配置，本工程采用原生 USB、手动按键及 GPIO21 驱动 RGB。

## 4. 现板检查未全通过

本次重新导出网表、运行 ERC、带原理图一致性检查的 DRC 及现有独立 QA。更换 R18 封装后已重新填铜，保留规则与原有布线。逐引脚网表在 L4 → R18 位号映射后与输入工程相同。

| 检查 | 结果 |
| --- | --- |
| 新导出网表与原交付网表的节点比较 | L4 → R18 位号映射后相同 |
| U1 管脚映射 | 41/41 对应 |
| Flash、晶振、EN/BOOT、USB、UART 连接及串阻检查 | 34/34 对应 |
| ERC | 0 项 |
| PCB 原理图一致性 / 未连接 | 0 / 0 项 |
| DRC | **2 项孔距违规** |
| 独立 QA | **43/48 通过，5 项失败** |

DRC 的两项为输入工程已有问题：C12.2 与 (110.0, 116.0) mm 的 U1 散热过孔重叠；C21.2 与 (109.0, 116.0) mm 的 U1 散热过孔重叠。两者都在背面焊盘与贯穿孔相遇处，规则要求孔边间距至少 0.10 mm。

QA 五项失败分别是：

1. C16、R6、AE1 的串联焊盘不共轴。该检查覆盖 C16，比当前布局约定中只要求 R6 与 AE1 馈电焊盘对齐更严格；本次保留检查并报告失败，没有将其等同于电气断路。
2. 天线与晶振本体间距为 5.100 mm，低于历史 8.5 mm 项目目标；该目标不是乐鑫保证值。
3. C12/C21 的孔到阻焊开窗间距不足。
4. 散热焊盘内孔清单不符合原 11 孔条件：当前脚本识别到 10 个符合位置与焊盘条件的保留孔；CSV 有 12 条“孔与焊盘相交”记录，其中两条是上述 C12/C21 与已有 U1 孔的重复关联，**不是发现了 12 个独立散热孔**。旧工艺清单需要在下次 PCB 修订时重新核对。
5. DRC 非零。

未把这些历史 PCB 问题扩展为本次重新布局任务，也未放宽规则或把失败改成通过。上电、晶振启动、频偏、无线发射供电、射频匹配和制板工艺均未进行实物验证。

## 5. 可复查记录

审查证据保存在 [output/esp32c6-review-20260909/](../output/esp32c6-review-20260909/)：

- [逐管脚清单](../output/esp32c6-review-20260909/u1-pin-audit.csv)及[外围连接结果和输入 SHA-256](../output/esp32c6-review-20260909/peripheral-audit.json)。
- [本次网表](../output/esp32c6-review-20260909/netlist.xml)、[ERC](../output/esp32c6-review-20260909/erc.json)、[DRC](../output/esp32c6-review-20260909/drc-final.json)及[QA](../output/esp32c6-review-20260909/qa.json)。
- [本次实际孔与焊盘相交记录](../output/esp32c6-review-20260909/via-in-pad.csv)，包含违规项，不作为允许装配的填孔清单。

根目录 `output/` 中的网表、ERC、DRC、QA 已同步为本次修正后的结果；以上审查目录保存同一组最终结果。修改前工程与导出文件备份位于 `tmp/crystal-0ohm-20260909-104814/`；PDF 文本、逐页渲染、官方原图和导出日志保留在 `tmp/esp32c6-audit/`。

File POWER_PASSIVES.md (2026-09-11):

# 阻容封装约定与变更记录

2026-09-10 最新 RGB 原理图：按用户确认采用官方 DevKitC-1 v1.4 阻值，R9 从 10 kΩ 改为 **3.3 kΩ**（GPIO8 → +3V3），R15 从 330 Ω 改为 **0 Ω**（数据节点 → DIN），R19 保持 **10 kΩ**（数据节点 → VBUS_USB）。三者均保持 0402 与默认装配；R/C 数量仍为 40。原理图、设计清单、BOM 和本页链接的阻容清单已同步，PCB 与贴装坐标留待用户 layout 后更新。见 [GPIO8 原理图记录](output/rgb-gpio8-schematic.json)。

2026-09-08，按用户最新决定：**射频匹配部分保持 0201，其余全部电阻、电容统一英制 0402（公制 1005，标称本体 1.0 × 0.5 mm）**。板框保持 20.5 × 32.0 mm。

## 当前范围

| 范围 | 位号 | 当前封装 |
| --- | --- | --- |
| 射频匹配 R/C，不改动 | C2、C3、C16、C17、C18、R6 | 0201 |
| 大容量电源电容，本次由 0603 改为 0402 | C8、C19、C20、C22、C23 | 0402 |
| Flash 串联电阻，本次由 0201 改为 0402 | R17、R1–R5 | 0402 |
| 其余非射频 R/C | C4–C7、C9–C15、C21、C24、C25、R7–R11、R14、R15、R19 | 0402 |
| 晶振串联电阻，2026-09-09 由原 L4 更正 | R18 = 0 Ω，对应官方模组 R4 | 0402 |

当前全部 R/C 共 40 个：6 个保留 0201，34 个使用 0402。2026-09-10 已按用户原理图删除 USB 的 R12、R13、C27、C28；同日 RGB 驱动改为二极管电平转换，删除 R16、C26 并新增 R19 = 10 kΩ 上拉，见 [USB 同步记录](output/usb-layout-sync.json) 与 [RGB 二极管驱动记录](output/rgb-diode-drive.json)。2026-09-08 有 11 个器件更换封装；2026-09-09 另将晶振串联器件从 L4 = 24 nH 电感改为 R18 = 0 Ω 电阻，采用标准 `Resistor_SMD:R_0402_1005Metric`，连接不变。依据为模组手册第 37、38 页的 R4，详见 [外围电路复核](docs/ESP32_C6_SCHEMATIC_REVIEW.md)。射频 L1、L3 及其他电感、芯片、保护器件保持原样。

原理图、PCB、设计清单与 BOM 同步，保持数值、网络和 DNP 状态。Flash 串阻在背面以 1.20 mm 间距对齐成一排，局部重新扇出；U3 与 D4 各向 USB 方向移动 0.80 mm，C7 位于正面的 VDD_SPI 扇出旁。U3 的两个填孔盖铜接地孔随有效焊盘位置调整，仍只保留全板 11 个该工艺例外。所有信号走线仍为 0.15 mm，非 GND 电源仍为 0.20 mm；普通过孔孔边到正反面 SMD 开窗至少 0.10 mm。

[output/passive-packages.csv](output/passive-packages.csv) 记录当前全部 40 个 R/C 的封装；[output/power-passives.csv](output/power-passives.csv) 保留 23 个电源、EN 定时及 USB-C 供电识别阻容的子集（C26 换为 R19）。`BeforeFootprint` 对原有器件指 2026-09-08 调整前，对新增记录 R18 指 2026-09-09 更正前的 L4 电感封装；`Footprint` 为当前封装，实际变化标记 `Changed=YES`，累计 12 条。独立 QA 按上述全部 R/C 规则核对，并检查 R18 的电阻符号、0 Ω 数值、装配状态和晶振网络。

## 大容量电容

| 位号 | 用途 | 标称容量 | 最低额定耐压 |
| --- | --- | --- | --- |
| C8 | 3.3V 主电源储能 | 10 µF | 10V |
| C19、C20 | V3A 射频电源储能 | 各 10 µF | 10V |
| C22 | 稳压器输入储能 | 10 µF | 10V |
| C23 | 稳压器输出储能 | 22 µF | 10V |

上述封装为 `Capacitor_SMD:C_0402_1005Metric`。BOM 的通用 MPN 仍为占位，未完成采购选型。此前查到的 Murata GRM155R61A106ME11（10 µF / 10V）与 GRM158R61A226ME15（22 µF / 10V）均为 X5R 参考系列，分别记载 0.7 / 0.8 mm 最大高度；仅说明此封装与容量组合存在，不代表选定具体可采购料号。

历史来源：[Murata 官方器件清单](https://www.murata.com/-/media/webrenewal/tool/library/common-pdf/dynamic-model/component-list-d-mlcc-2506.ashx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)。采购时须按最新资料核对用途限制、温度范围、供货、完整后缀与直流偏压曲线，不能把大容量参考件写成已选定的 X7R。

0402 MLCC 在实际 3.3V / 5V 偏压下的有效容量可能明显低于标称值。样板应核对稳压器稳定性、无线发射时电源压降和纹波；目前没有实板有效容量、电源或射频性能测量结论。标准库 3D 模型只表示位置，不能代替实际器件高度确认。

## 历史经过

1. 2026-09-08，为尝试 18 × 30 mm，将五颗大容量电容由 0603 改为 0402；缩板候选未完成布线，记录见 [SHRINK_TRIAL.md](SHRINK_TRIAL.md)。
2. 同日曾恢复五颗 0603 以便焊接；随后板头收短，尺寸变为 20.5 × 32.0 mm。
3. 本次按最新决定统一非射频 R/C 为 0402，并把 U1 相关外围移至主原理图用实线连接。此前恢复 0603 的决定不再是当前约定。

当前检查结果以 [QA](output/qa.json)、[DRC](output/drc-final.json) 和 [ERC](output/erc.json) 为准。修改前备份与逐次命令、原始输出位于本地 `tmp/nonrf-0402-direct-schematic-20260908-151123/`。

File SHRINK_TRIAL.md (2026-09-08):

# 18 × 30 mm 缩板尝试记录

2026-09-08，目标是在电源阻容统一为 0402 后，将当前 20.5 × 32.5 mm PCB 尝试缩至 18 × 30 mm。

**历史结果：已完成目标尺寸的器件试排和多轮布线尝试，但没有完成全板连通。当时主工程保留 20.5 × 32.5 mm，仅合入通过检查的 0402 修改。随后用户决定将 C8、C19、C20、C22、C23 恢复为 0603，现已执行。后来主板另从板头收短 0.5 mm 至 20.5 × 32.0 mm；以下 18 × 30 mm 候选与报告保留原样作为历史证据。** 这次尝试不能证明 18 × 30 mm 在其他布局下不可实现。

## 候选布局与约束

- 目标面积 540 mm²，较当前 666.25 mm² 减少约 18.95%。
- 陶瓷天线横向居中，板头全层净空 18 × 4 mm；晶振与负载电容保留在主控右侧。
- 两排 2.00 mm 排针从背面安装，候选列中心距 15.70 mm；编号和网络顺序保留。
- Flash 与 USB TVS 保留在背面，TVS 旋转以缩短占用高度；两颗按键保留在正面。
- 电源、主控去耦和局部器件重新安排，射频、时钟、USB 与主控 Flash 关键连接单独布线。
- 保留四层及 L2 接地参考，信号 0.15 mm、非 GND 电源 0.20 mm；没有降低正式工程的铜间距、孔距及阻焊开窗要求。

## 检查结果和未完成项

目标板框、器件庭院、射频/晶振层使用、晶振间距与接地参考、排针编号、0402 封装和孔边到 SMD 开窗等几何检查通过。经过三轮全局布线及一轮局部补线，最后候选仍有 **18 处未连接、17 项 DRC 违规**；独立 QA 总体未通过。

未连接包括部分 Flash 串联电阻到背面 Flash 的连接、主控 GPIO 及部分供电支路。Flash 的背面中心焊盘限制了正面串联电阻附近的换层位置，主控两侧现有扇出和器件进一步压缩了绕线空间。局部补线在这些固定位置未找到合规通道。

17 项 DRC 为 9 项板边退铜不足、7 项单端未接通的过孔及 1 项短悬空线段。板边问题的实际间距约 0.2083 mm，小于现有 0.25 mm 规则。另外，局部补线新增普通孔尚未全部显式设为双面盖油。没有豁免上述问题，也没有把候选替换为主工程。

若以后继续尝试该尺寸，需要重新分配 Flash 串联电阻和主控的出线空间，并调整排针外侧走线余量；仅缩小板框或继续微调现有走线不足以形成可交付结果。本轮没有实板、射频或电源性能测量。

## 本地证据

临时候选、备份和原始日志均在已忽略的本地目录，未作为生产输出：

- [未完成的 18 × 30 mm PCB](tmp/power-0402-18x30-20260908-101555/work/esp32-c6-pico.kicad_pcb)
- [候选 DRC](tmp/power-0402-18x30-20260908-101555/work/output/drc-final.json) 与 [候选 QA](tmp/power-0402-18x30-20260908-101555/work/output/qa.json)
- [候选正面试排图](tmp/power-0402-18x30-20260908-101555/compact-front.svg) 与 [背面试排图](tmp/power-0402-18x30-20260908-101555/compact-back.svg)
- [局部补线结果](tmp/power-0402-18x30-20260908-101555/finish-compact-01.json.results.json)
- 同目录的 `*.command.json`、`*.stdout.log`、`*.stderr.log` 和 `*.exit-code.txt` 保留每轮命令及未经改写的输出。

当前主工程已将上述五颗大容量电容恢复为 0603，其余 18 个相关阻容保留原有 0402；恢复记录见 [POWER_PASSIVES.md](POWER_PASSIVES.md)。

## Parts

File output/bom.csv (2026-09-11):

Reference | Value | MPN | Footprint | Populate | Note
U1 | ESP32-C6 | ESP32-C6 | Pico:QFN40_ESP32_C6_Compact | YES | QFN40, NOT the pin-incompatible C6FH4 QFN32
C3 | 1.5pF | 1.5pF | Capacitor_SMD:C_0201_0603Metric | YES | C0G; RF initial value, VNA tuning required
L1 | 2.4nH | 2.4nH | Inductor_SMD:L_0201_0603Metric | YES | High-Q RF; initial value
C2 | 1.5pF | 1.5pF | Capacitor_SMD:C_0201_0603Metric | YES | C0G; RF initial value
C16 | 10pF | 10pF | Capacitor_SMD:C_0201_0603Metric | YES | C0G DC-block / tuning initial value
L3 | DNP | DNP | Inductor_SMD:L_0201_0603Metric | NO | Shunt RF tuning option
C17 | DNP | DNP | Capacitor_SMD:C_0201_0603Metric | NO | Antenna pi input shunt
R6 | 0R | 0R | Resistor_SMD:R_0201_0603Metric | YES | Antenna pi series tuning option
C18 | DNP | DNP | Capacitor_SMD:C_0201_0603Metric | NO | Antenna pi output shunt
AE1 | RFANT5220110A0T | RFANT5220110A0T | Walsin_Antenna:RFANT5220110A0T | YES | Pad 2 stays open with axial end copper; right-aligned horizontal prototype, 20x3.8 mm all-layer clearance; RF validation required
D1 | PESD5V0F1BL-Q | PESD5V0F1BL-Q | Diode_SMD:D_SOD-882 | NO | 0.4 pF antenna ESD option; original 15 pF ESD9B is unsuitable
C8 | 10uF | 10uF | Capacitor_SMD:C_0402_1005Metric | YES | Main bulk; 0402, 10 V minimum; X5R reference; verify effective capacitance under DC bias
C9 | 1uF | 1uF | Capacitor_SMD:C_0402_1005Metric | YES | Main bulk; X7R 10 V minimum
C10 | 100nF | 100nF | Capacitor_SMD:C_0402_1005Metric | YES | Main HF; X7R 10 V minimum
C12 | 100nF | 100nF | Capacitor_SMD:C_0402_1005Metric | YES | U1 pin 5; X7R 10 V minimum
C13 | 100nF | 100nF | Capacitor_SMD:C_0402_1005Metric | YES | U1 pin 28; X7R 10 V minimum
C14 | 100nF | 100nF | Capacitor_SMD:C_0402_1005Metric | YES | U1 pin 37; X7R 10 V minimum
C15 | 100nF | 100nF | Capacitor_SMD:C_0402_1005Metric | YES | U1 pin 40; X7R 10 V minimum
L2 | 2.0nH | 2.0nH | Inductor_SMD:L_0402_1005Metric | YES | RF supply filter; Irated >= 500 mA, low DCR
C11 | 1uF | 1uF | Capacitor_SMD:C_0402_1005Metric | YES | U1 pins 2/3 local bypass
C19 | 10uF | 10uF | Capacitor_SMD:C_0402_1005Metric | YES | U1 pin 2 local bulk; 0402, 10 V minimum; verify effective capacitance under DC bias
C20 | 10uF | 10uF | Capacitor_SMD:C_0402_1005Metric | YES | U1 pin 3 local bulk; 0402, 10 V minimum; verify effective capacitance under DC bias
U3 | W25Q32JVSNIQ | W25Q32JVSNIQ | Package_SO:SOIC-8_3.9x4.9mm_P1.27mm | YES | SOIC-8 150 mil; 3.9 x 4.9 mm body; no exposed pad; 4 MB, 2.7-3.6 V
R17 | 0R | 0R | Resistor_SMD:R_0402_1005Metric | YES | Place at U1; SPI clock defaults to 40 MHz for bring-up
R1 | 0R | 0R | Resistor_SMD:R_0402_1005Metric | YES | Place at U1; SPI clock defaults to 40 MHz for bring-up
R2 | 0R | 0R | Resistor_SMD:R_0402_1005Metric | YES | Place at U1; SPI clock defaults to 40 MHz for bring-up
R3 | 0R | 0R | Resistor_SMD:R_0402_1005Metric | YES | Place at U1; SPI clock defaults to 40 MHz for bring-up
R4 | 0R | 0R | Resistor_SMD:R_0402_1005Metric | YES | Place at U1; SPI clock defaults to 40 MHz for bring-up
R5 | 0R | 0R | Resistor_SMD:R_0402_1005Metric | YES | Place at U1; SPI clock defaults to 40 MHz for bring-up
C6 | 100nF | 100nF | Capacitor_SMD:C_0402_1005Metric | YES | At flash VCC
C7 | 1uF | 1uF | Capacitor_SMD:C_0402_1005Metric | YES | At U1 VDD_SPI pin
R18 | 0R | 0R | Resistor_SMD:R_0402_1005Metric | YES | Crystal series link; 0R per ESP32-C6-WROOM-1/1U v1.4 figs 8-1/8-2 (R4); former L4
Y1 | 40MHz / CL=8pF | E9X400081G08 | Crystal:Crystal_SMD_2016-4Pin_2.0x1.6mm | YES | Eaton E9X; 40 MHz, CL 8 pF, initial tolerance 10 ppm, ESR <=50 ohm; verify assembled frequency
C4 | 12pF | 12pF | Capacitor_SMD:C_0402_1005Metric | YES | C0G; assumes about 2 pF stray; trim frequency on hardware
C5 | 12pF | 12pF | Capacitor_SMD:C_0402_1005Metric | YES | C0G; crystal load tuning
J1 | USB4105-GF-A | USB4105-GF-A | Connector_USB:USB_C_Receptacle_GCT_USB4105-xx-A_16P_TopMnt_Horizontal | YES
R10 | 5.1k | 5.1k | Resistor_SMD:R_0402_1005Metric | YES | 1%; one Rd per CC pin
R11 | 5.1k | 5.1k | Resistor_SMD:R_0402_1005Metric | YES | 1%; USB-C sink, no PD
D4 | USBLC6-2SC6 | USBLC6-2SC6 | Package_TO_SOT_SMD:SOT-23-6 | YES
D3 | ESD9B5.0ST5G | ESD9B5.0ST5G | Diode_SMD:D_SOD-923 | YES | Move original 15 pF TVS to USB power rail
D5 | BAT760-7 | BAT760-7 | Diode_SMD:D_SOD-323 | YES | Same part/package as at820_tiga D9/D10; 30 V, 1 A with datasheet thermal derating; blocks USB backfeed
U2 | AP2112K-3.3 | AP2112K-3.3TRG1 | Package_TO_SOT_SMD:SOT-23-5 | YES | 600 mA peak rating; continuous load limited by SOT25 dissipation
C22 | 10uF | 10uF | Capacitor_SMD:C_0402_1005Metric | YES | Regulator input; 0402, 10 V minimum; X5R reference; verify effective capacitance under DC bias
C23 | 22uF | 22uF | Capacitor_SMD:C_0402_1005Metric | YES | Regulator output; 0402, 22 uF nominal, 10 V minimum; X5R reference; verify effective capacitance under DC bias
C24 | 100nF | 100nF | Capacitor_SMD:C_0402_1005Metric | YES
R7 | 10k | 10k | Resistor_SMD:R_0402_1005Metric | YES
C21 | 1uF | 1uF | Capacitor_SMD:C_0402_1005Metric | YES
SW1 | RESET | KMR221GLFS | Button_Switch_SMD:SW_Push_1P1T_NO_CK_KMR2 | YES
R8 | 10k | 10k | Resistor_SMD:R_0402_1005Metric | YES
SW2 | BOOT | KMR221GLFS | Button_Switch_SMD:SW_Push_1P1T_NO_CK_KMR2 | YES
R9 | 3.3k | 3.3k | Resistor_SMD:R_0402_1005Metric | YES | GPIO8 strapping pull-up; 3.3k to 3V3 per DevKitC-1 v1.4 R6
R14 | 499R | 499R | Resistor_SMD:R_0402_1005Metric | YES | UART0 harmonic damping at U1
J2 | J2 GPIO / 2.00mm | 1x12 P2.00 vertical header | Pico:PinHeader_1x12_P2.00mm_Compact | YES
J3 | J3 GPIO / 2.00mm | 1x12 P2.00 vertical header | Pico:PinHeader_1x12_P2.00mm_Compact | YES
D6 | 1N4148WS | 1N4148WS-7-F | Diode_SMD:D_SOD-323 | YES | Silicon switching diode level shift: cathode to GPIO8, anode to the pulled-up WS2812B data node
R19 | 10k | 10k | Resistor_SMD:R_0402_1005Metric | YES | WS2812B data pull-up to the USB 5 V rail
R15 | 0R | 0R | Resistor_SMD:R_0402_1005Metric | YES | RGB data series link; 0R per DevKitC-1 v1.4 R17
D2 | WS2812B-2020 | WS2812B-2020 | LED_SMD:LED_WS2812B-2020_PLCC4_2.0x2.0mm | YES
C25 | 1uF | 1uF | Capacitor_SMD:C_0402_1005Metric | YES | At RGB VDD

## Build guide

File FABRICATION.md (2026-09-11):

# Rev A 工艺与样板验证

2026-09-11 第一版提交快照：已保留用户后续调整的 R19 / R15 位置、局部短线和图形，重新填铜并更新当前贴装坐标、二维装配图及检查报告。ERC 0、DRC 错误 0 / 丝印警告 1、未连接 0、一致性问题 0，独立 QA 39/53；未进行实板验证。以 [第一版提交记录](output/first-pcb-revision.json) 及当前坐标、装配图为准，下文居中过程记录与旧 3D 图保留作历史参考。

2026-09-10 最新 PCB 微调：USB 与两颗按键已按 X=110.00 mm 中心线居中，D2 位号丝印隐藏；为避让定位孔及按键庭院，另微移 D4 / R15。器件参数、封装、安装面、网络、板框与 89 个过孔总数保持输入状态。请使用本轮更新的 `output/placement.csv` 和正反面二维装配图；旧 3D 图及下文先前轮次的布局说明为历史记录。重填铜后 ERC 0、DRC 错误 0、未连接 0、一致性 0，保留原有 1 项板头丝印重叠警告；独立 QA 39/53，与输入基线相同，无新增失败项。本次只验证局部修改，未进行实板测试，不能称全板 QA 通过。范围和证据见 [居中记录](output/usb-buttons-centered.json)。

2026-09-10 最新状态：本轮仅修改原理图，RGB 控制切回 GPIO8，GPIO21 标记不连接；PCB 和贴装坐标保持输入状态，须由用户更新布局后重新填铜并运行 DRC / QA。已按用户确认对齐官方阻值：R9 = 3.3 kΩ 上拉 GPIO8 到 3.3 V，R19 = 10 kΩ 上拉数据节点到 5 V，R15 = 0 Ω 串联接入 DIN；保留二极管两侧的上拉，均采用原 0402 封装。新 BOM 按原理图更新，贴装坐标仍属于旧 PCB 状态。新 ERC 为 0；下列布局报告属于此前状态，不证明与新原理图一致。详见 [GPIO8 原理图记录](output/rgb-gpio8-schematic.json)。

2026-09-10 此前 RGB 驱动同步：删除 U4（SN74LV1T125）、去耦 C26 与下拉 R16，新增 D6（1N4148WS / SOD-323，背面）和 R19（10 kΩ 0402，正面），R15 = 330 Ω 移到 D2 的 DIN 焊盘旁。当前 59 个器件位、55 个默认装配；ERC 0、原理图一致性 0，DRC 5 项违规、9 项未连接、QA 45/53，与本轮改动前同一工程的基线逐项一致，剩余项来自尚未完成的 J3 排针布线，**投板前必须清零**。装配面：D6 在背面，D2、R19、R15 在正面；BOM、贴装坐标与装配图已同步。最新交付见 [RGB 二极管驱动记录](output/rgb-diode-drive.json)。

2026-09-10 此前 USB 同步：R12、R13、C27、C28 已从原理图、PCB、BOM 和装配图删除，数据线直接连接主控；保留 CC 下拉和 D4 TVS。该轮为 60 个器件位、56 个默认装配，ERC / DRC / 未连接 / 一致性均为 0，QA 48/52；四项既有失败仍须按报告处理。补接了输入板原有的 U3.4 地铜孤岛，普通过孔现均明确双面盖油，Y1 接地孔距离检查通过。板框和 60 个保留器件位置不变。以下历次调整记录中的旧器件数、待连接状态和工艺检查结果仅作历史参考；最新交付见 [USB 同步记录](output/usb-layout-sync.json)。

2026-09-10 左侧收窄：板框现为 **18.0 × 29.0 mm**，左板边与 J2 同步右移 **2.00 mm（四个 0.50 mm 步长）**，面积由 580 降至 522 mm²，减少 10%。J2 / J3 中心 X 为 102.25 / 117.75 mm，列中心距 15.50 mm；针距仍为 2.00 mm，焊盘铜到两侧板边仍各 0.575 mm。为避让左排针，仅另调整背面的 C8、C28、R8，其他 60 个器件保持位置、安装面和封装，L2、RF/晶振走线及 USB 数据主干保持不动。J2 第 4 / 5 脚改为 GPIO2 / GPIO1，原理图、设计清单及背面丝印已同步。

**按用户要求保留唯一一条手动连接：GPIO5，U1.11 → J2.8。** U1 焊盘中心为 (106.5625, 115.20) mm，J2 焊盘中心为 (102.25, 128.00) mm；该网络已清除未完成的线头，打开 KiCad 后可直接按飞线补接，信号宽度为 0.15 mm，In1.Cu 继续留作 GND。当前 **ERC 0、DRC 违规 0、原理图一致性 0、未连接 1；QA 45/52**。QA 保留原有六项失败，新增的一项失败就是这条明确预留的连接，未放宽检查。总过孔由 125 减至 124。完成 GPIO5 后须重填铜并重新运行 DRC / QA；当前不是已全部布线的生产文件。范围、备份与端点见 [18 mm 收窄记录](output/width-18mm.json)。

2026-09-09 L2 换面：2 nH / 0402 的射频供电滤波电感移至 B.Cu，中心 (111.55, 112.65) mm；C11/C19/C20 及其正面连接保持不动。输出通过 (110.50, 112.80) mm 的 0.30 / 0.15 mm 双面盖油过孔接回正面 V3A，孔边到两面 SMD 开窗通过原有 0.10 mm 检查；移除原 L2 输入支路闲置过孔，总孔数不变。其余器件、RF/晶振/USB 信号线及禁布区不变。当前 DRC、未连接和原理图一致性均为 0，QA 46/52，六项既有失败不变；详见 [L2 迁移记录](output/l2-back-migration.json)。换层后的供电与射频表现尚未实板验证，装配使用更新后的背面视图及坐标。

本文件随 18.0 × 29.0 mm 可编辑 PCB 交付。2026-09-09 Flash / 二极管封装替换后，ERC、DRC、原理图一致性和连通性均为 0 项；独立 QA **45/51 通过**，修改前实际文件为 43/49，无新增失败项。六项既有问题包括 MCU 接地孔数量、天线匹配器件共轴、天线/晶振间距、晶振接地过孔距离、MCU 散热孔清单及一颗普通过孔未显式双面盖油。详细范围和备份路径见 [封装替换记录](output/package-changes.json)。F1 已按用户要求删除，USB 电源直接连接 D5 阳极；器件位置保持删除前布局。尚未完成实物验证。

## PCB 工艺

| 项目 | 当前设计 |
| --- | --- |
| 板框 | 18.00 × 29.00 mm；USB 金属壳略伸出板边 |
| 层数 / 厚度 | 四层；标称 0.80 mm |
| 排针安装 / 间距 | 背面安装；针距 2.00 mm；两列中心距 15.50 mm；焊盘距侧边 0.575 mm |
| 顶层 / 底层铜 | 35 µm 名义值 |
| 内层铜 | 17.5 µm 名义值 |
| 顶层到 L2 介质 | 0.100 mm 名义值，FR4，设计用 εr=4.2 |
| L2 到 L3 介质 | 0.495 mm 名义值 |
| L3 到底层介质 | 0.100 mm 名义值 |
| 最小线宽 / 铜间距 | 0.10 / 0.10 mm |
| 实际信号 / 非 GND 电源走线 | 固定 0.15 / 0.20 mm，含焊盘扇出；GND 保留原有线宽 |
| 普通过孔 | 主要为 0.45 mm 焊盘 / 0.20 mm 钻孔 |
| 紧凑扇出过孔 | 0.30 mm 焊盘 / 0.15 mm 钻孔；部分 0.40 / 0.20 mm |
| 最小过孔环宽 | 0.075 mm |
| 孔到其他铜 / 孔到孔 | 0.18 / 0.20 mm 规则值 |
| 普通过孔孔边到 SMD 开窗 | 至少 0.10 mm；同时检查正反面及同网络焊盘 |
| 板边退铜 | 0.25 mm 规则值 |
| 表面处理 | 建议沉金；细间距 QFN、0201 与双面贴装 |

以上介质厚度用于设计与阻抗初算，并不是任何制板厂已确认的现货叠层。请先让板厂给出可生产的 0.8 mm 叠层，再回算 RF 50 Ω 单端及 USB 90 Ω 差分线宽/间距。不得仅依据文件内的目标阻抗认定成品已达标。

第二层为 GND 参考，天线区与第一只 RF 接地电容短支节下方有明确例外。射频和晶振信号均不换层。横放天线位于右侧、开路端铜箔向左展开；板头 **18.0 × 3.8 mm** 范围所有铜层不铺铜。两侧禁止走线区域均延伸至 Y=112.30 mm，仅在天线馈电焊盘下方保留直线馈线通道，R6 与 AE1 馈电焊盘的 X 坐标均为 116.12 mm。

该横放布局优先减少面积，偏离厂商纵向参考测试板。末端铜块的 3.3 × 1.5 mm 面积及 0.5 × 1.2 mm 细连接保留，两只焊接焊盘尺寸和间距不变；末端铜不印锡膏、不接地。轴向铜箔、3.8 mm 净空与缩短地平面的 S11、效率和通信表现待实板验证。

2026-09-09：在 28 mm 版上将板头加长 1 mm，天线向右移动 4.42 mm、向板头移动 1 mm，Codex 图标移到左侧。当前板长 29 mm，新增长度全部用于板头净空，地平面上边界和其余器件位置保持不动。馈线从 6.07 mm 的折返路径改为 2.65 mm 的直线；本轮未新增过孔。

正面 Codex 图标在 PCB 中约 2.1 mm，背面个人图形画布高约 4.51 mm，主体轮廓保留约 0.12 mm。源 SVG 尺寸保持原样，PCB 内分别按 75% 和 55% 缩放。图形位于 F.SilkS / B.SilkS，仅作丝印；天线禁布以 PCB 规则区为准。源图和位置参数见 [docs/logo/README.md](docs/logo/README.md)。

## MCU 散热焊盘内过孔

SOIC-8 Flash 没有中心焊盘，原 U3.9 网络端点及其工艺例外已删除，原 (108.58, 123.20) mm 接地孔改为普通双面盖油。当前仅允许 **U1.41 的 9 个中心接地孔**；独立 QA 实际识别到 **7 个**，与修改前 MCU 状态一致，见 `output/via-in-pad.csv`。原先 U1 九孔加 U3 两孔的 11 孔目标属于 WSON 版本，不能继续用于当前 SOIC-8 工程。

这 7 个实际保留孔已设置 Filling / Capping 属性，须采用**填孔后电镀盖铜（VIPPO）**；生产前仍须解决 MCU 缺少两孔的既有问题。普通盖油不能替代填孔盖铜。外围引脚、小器件和 USB 焊盘到普通孔的孔边间距至少 0.10 mm，正反面、同网络及 DNP 焊盘均参与检查。`.kicad_dru` 与独立 QA 已移除 U3 例外，保留 U1 的九孔位置要求。

普通过孔须双面盖油；输入设计在 (113.825, 121.780854) mm 的一颗过孔未显式设置双面盖油，本轮保留原状，QA 继续报告失败。板厂须确认 0.15 mm 钻孔、0.075 mm 环宽及板厚组合。可参考[嘉立创过孔覆盖说明](https://jlcpcb.com/help/article/pcb-via-covering)与[多层板工艺说明](https://www.jlc.com/portal/q7i38752.html)，实际能力与费用以工厂审核为准。

本板尺寸小且双面贴装，应由装配厂确认拼板方案，在工艺边补足其要求的基准点、定位孔和夹持空间。贴片坐标原点设在板框左下角；导出的背面旋转角需要按贴片厂格式复核。原生 KiCad 坐标文件没有自动转换成某家工厂专有的角度规则。

## 电源器件封装

D5 采用参考工程 `at820_tiga/power.kicad_sch` 中 D9/D10 同款 **BAT760-7 / SOD-323**，替代 SS14FL / SOD-123F；阴极 1 脚仍接 +5V，阳极 2 脚在删除 F1 后直接接 VBUS_USB。[Diodes 数据手册](https://www.diodes.com/datasheet/download/BAT760.pdf)规定 30 V、1 A（额定电流受端子温度及散热条件限制），不能将小封装的额定值当成本板连续负载验证。按当前 KiCad 庭院包围尺寸，D5 占位约从 4.49 × 2.39 mm 变为 3.29 × 1.99 mm。

U3 按 [Winbond 数据手册](https://www.winbond.com/resource-files/w25q32jv%20revg%2003272018%20plus.pdf)的 150 mil SOIC-8 封装与 [官方选型表](https://www.winbond.com/export/sites/winbond/product-selection-guide/file/2025-Product-Selection-Guide-Winbond-Code-Storage-Flash-Memory.pdf)中的 W25Q32JVSNIQ 配套。不可采购 208 mil 的 W25Q32JVSSIQ 装到这块板上。原 1–8 脚功能、2.7–3.6 V 供电及 4 MB 容量不变。

F1 已从原理图、PCB、BOM 和装配坐标删除，不再保留保险丝或磁珠焊盘。`VBUS_FUSED` 合并到 `VBUS_USB`，USB 电源直接接 D5 阳极；D5 的防反灌作用保留。本轮只缩短原 F1 支路的电源走线，其余 64 个器件位置、全部过孔和信号走线几何不变，板框保持 20 × 29 mm。

## 电源与基础功能验证

- 先在限流供电下检查无短路、3.3 V 稳压和 EN 上电波形，再测试 USB 枚举、下载、复位和 BOOT 强制下载。
- 采用可提供至少 500 mA 的 USB 电源端口。测量无线发射时芯片端 3.3 V 的最低值、VDD_SPI、供电纹波及 AP2112 温升。
- AP2112 的 600 mA 额定值不是本板可对外提供 600 mA 的承诺。持续负载能力受输入压差、环境温度和散热面积限制，应在实测之后确定外接负载余量。
- C8/C19/C20/C22 的 10 µF 与 C23 的 22 µF 使用英制 0402（公制 1005），最低 10V 耐压；除 6 个射频匹配电阻/电容保持 0201 外，其余全部阻容均为 0402。当前封装和变更记录见 [POWER_PASSIVES.md](POWER_PASSIVES.md)。10/22 µF 陶瓷电容须按实际工作电压检查有效容值。L2 需选择额定电流不低于 500 mA、低直流电阻的 2 nH 电感；不能仅按电感值替换。
- Flash 使用 W25Q32JVSNIQ / SOIC-8 150 mil（3.9 × 4.9 mm 本体），按 4 MB 识别。建议先用保守的 DIO / 40 MHz 设置验证下载、擦写与重启，再测试 QIO。

Flash U3、USB TVS D4、RGB 电平转换二极管 D6 和两排排针 J2 / J3 位于背面；SW1 / SW2、晶振及其负载电容、RGB 灯 D2 与 R19 / R15 位于正面。排针塑料座和长针在背面，正面保留焊接端，本轮同时检查通孔焊盘与两面的器件庭院。两列中心距现为 15.50 mm（最新一轮仅 J2 向右移动 2.00 mm），沿列针距仍为 2.00 mm，1 脚均靠近天线。装配坐标原点设在板框左下角；请使用更新后的 `output/placement.csv` 和正反面装配图。

## 晶振与天线隔离

晶振 Y1、C4、C5 与串联电阻 R18（原 L4）保持输入位置和走线；R18 按模组图采用 0 Ω、0402 电阻。排针保留背面安装。板框为 18.0 × 29.0 mm，天线横放在板头右侧，板头全层不铺铜区为 18.0 × 3.8 mm。

晶振与天线名义本体边缘最近距离约 **5.070 mm**，低于历史 **8.5 mm** 项目目标；该目标不是厂商保证，本轮也没有将其调低来取得 QA 通过。晶振本体到芯片时钟引脚的约 2.800 mm 间距及约 11.850 mm 时钟走线保持输入布局，信号全部在顶层且不换层。

`XTAL_REFERENCE` 保持晶振下方 2.40 × 2.50 mm 的参考区：背面和两层内层禁止走线及焊盘，并禁止非接地过孔穿过，允许接地填铜。该规则区和晶振位置保持输入状态。晶振串联电阻修正后已重填铜，独立 QA 确认 L2 GND 完整覆盖参考区及晶振本体投影。

本轮复核 Y1.2 / Y1.4 / C4.2 / C5.2 到最近接地过孔的中心距离分别为 2.550 / 0.886 / 0.861 / 0.764 mm。Y1.2 仍超过 1 mm 项目目标，该项在修改前也失败；其余三项满足。布局依据为[乐鑫 ESP32-C6 晶振与射频指南](https://docs.espressif.com/projects/esp-hardware-design-guidelines/en/latest/esp32c6/pcb-layout-design.html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)。

C16 到 R6 恢复为较短的直线馈电段。板宽、主地面积及晶振位置均有变化，仍需在样板上复测匹配、频偏、启动和收发性能；当前没有隔离度或接收灵敏度的实测结论。

## RF、时钟与 USB

RF 默认值为 C3=1.5 pF、L1=2.4 nH、C2=1.5 pF、C16=10 pF；L3、C17、C18、D1 不装，R6=0 Ω。它们是调试起点，不是经过本板测量得到的最终匹配值。天线的开路端必须保持开路，不能把 AE1 的 2 脚接地。

预留 π 网络供天线匹配；可在拆下 R6 后通过合适的射频夹具接入测试设备。需要验证匹配、发射谐波、频偏、吞吐量和距离，并在最终外壳及典型 USB 连接状态下复测。晶振 Y1 选 E9X400081G08（40 MHz、CL=8 pF）；两只 12 pF 负载电容按约 2 pF 杂散电容估算，最终以实际频偏调整。

USB 主干采用正反面 0.15 mm 走线，每根线各有两次换层；TVS 紧靠 USB-C 数据焊盘布置。芯片、TVS 与连接器处按焊盘排列扇出，不为数值等长加入蛇形补偿。删除 USB 串阻和选装电容后，按铜线中心线及标称 0.8 mm 过孔贯穿长度估算，A 组 D+/D− 约 25.802/26.228 mm，B 组约 24.474/23.152 mm，最大长度差约 1.322 mm。该统计不包含器件内部或 USB 线缆，不能替代阻抗场求解或 USB 实测。

所有信号（含 RF、晶振和 USB）统一为 0.15 mm，非 GND 电源统一为 0.20 mm；GND 走线和填铜延续原设计。`Power` 类包括 `+3V3`、`+5V`、`V3A`、`VBUS_USB` 和 `VDD_SPI`，`.kicad_dru` 对信号、电源分别设置相等的最小/默认/最大线宽。既有铜间距、孔距、焊盘开窗和板边规则继续生效。电源主干变窄后须在样板上核对发射负载下的压降与温升；0.15 mm 的 RF/USB 线宽仍需结合板厂叠层确认阻抗。

完成以上验证后，才能确定量产匹配值、负载能力和最终制板参数。确认叠层与焊盘内孔工艺后，再生成与工厂确认参数一致的生产 Gerber。

2026-09-09 历史板宽调整：左右板边各内收 0.25 mm，外框 X=99.00–119.00 mm、Y=108.50–137.50 mm。排针焊盘仍为 1.35 mm、孔径 0.80 mm，铜外缘到左右板边各 0.275 mm；器件、过孔和走线位置不动。装配坐标使用更新后的板左下角原点 (99.00, 137.50) mm。

2026-09-09 排针内移：保持上述 20.00 × 29.00 mm 板框及坐标原点，J2 从 X=99.95 移到 100.25 mm，J3 从 X=118.05 移到 117.75 mm；中心距为 17.50 mm。焊盘和孔径仍为 1.35 / 0.80 mm，铜外缘到侧边各 0.575 mm。按封装标称 2.00 mm 宽塑料座计算，本体距侧边各 0.25 mm；该余量为标称几何值。

本次局部避让：J3 的 +5V 与 GPIO10 绕过移入后的通孔；GPIO11 在晶振禁布区外设置两颗双面盖油过孔，经正面通过狭窄通道；GPIO15 直接接排针通孔，去掉原先多余的换层过孔。一颗 GND 缝合孔移至 (116.40, 118.20) mm，保持接地并缩短 Y1.4 / C5.2 的接地孔距离。其余 63 个器件、板框、禁布区及 RF / 晶振 / USB 走线均与输入文件一致。

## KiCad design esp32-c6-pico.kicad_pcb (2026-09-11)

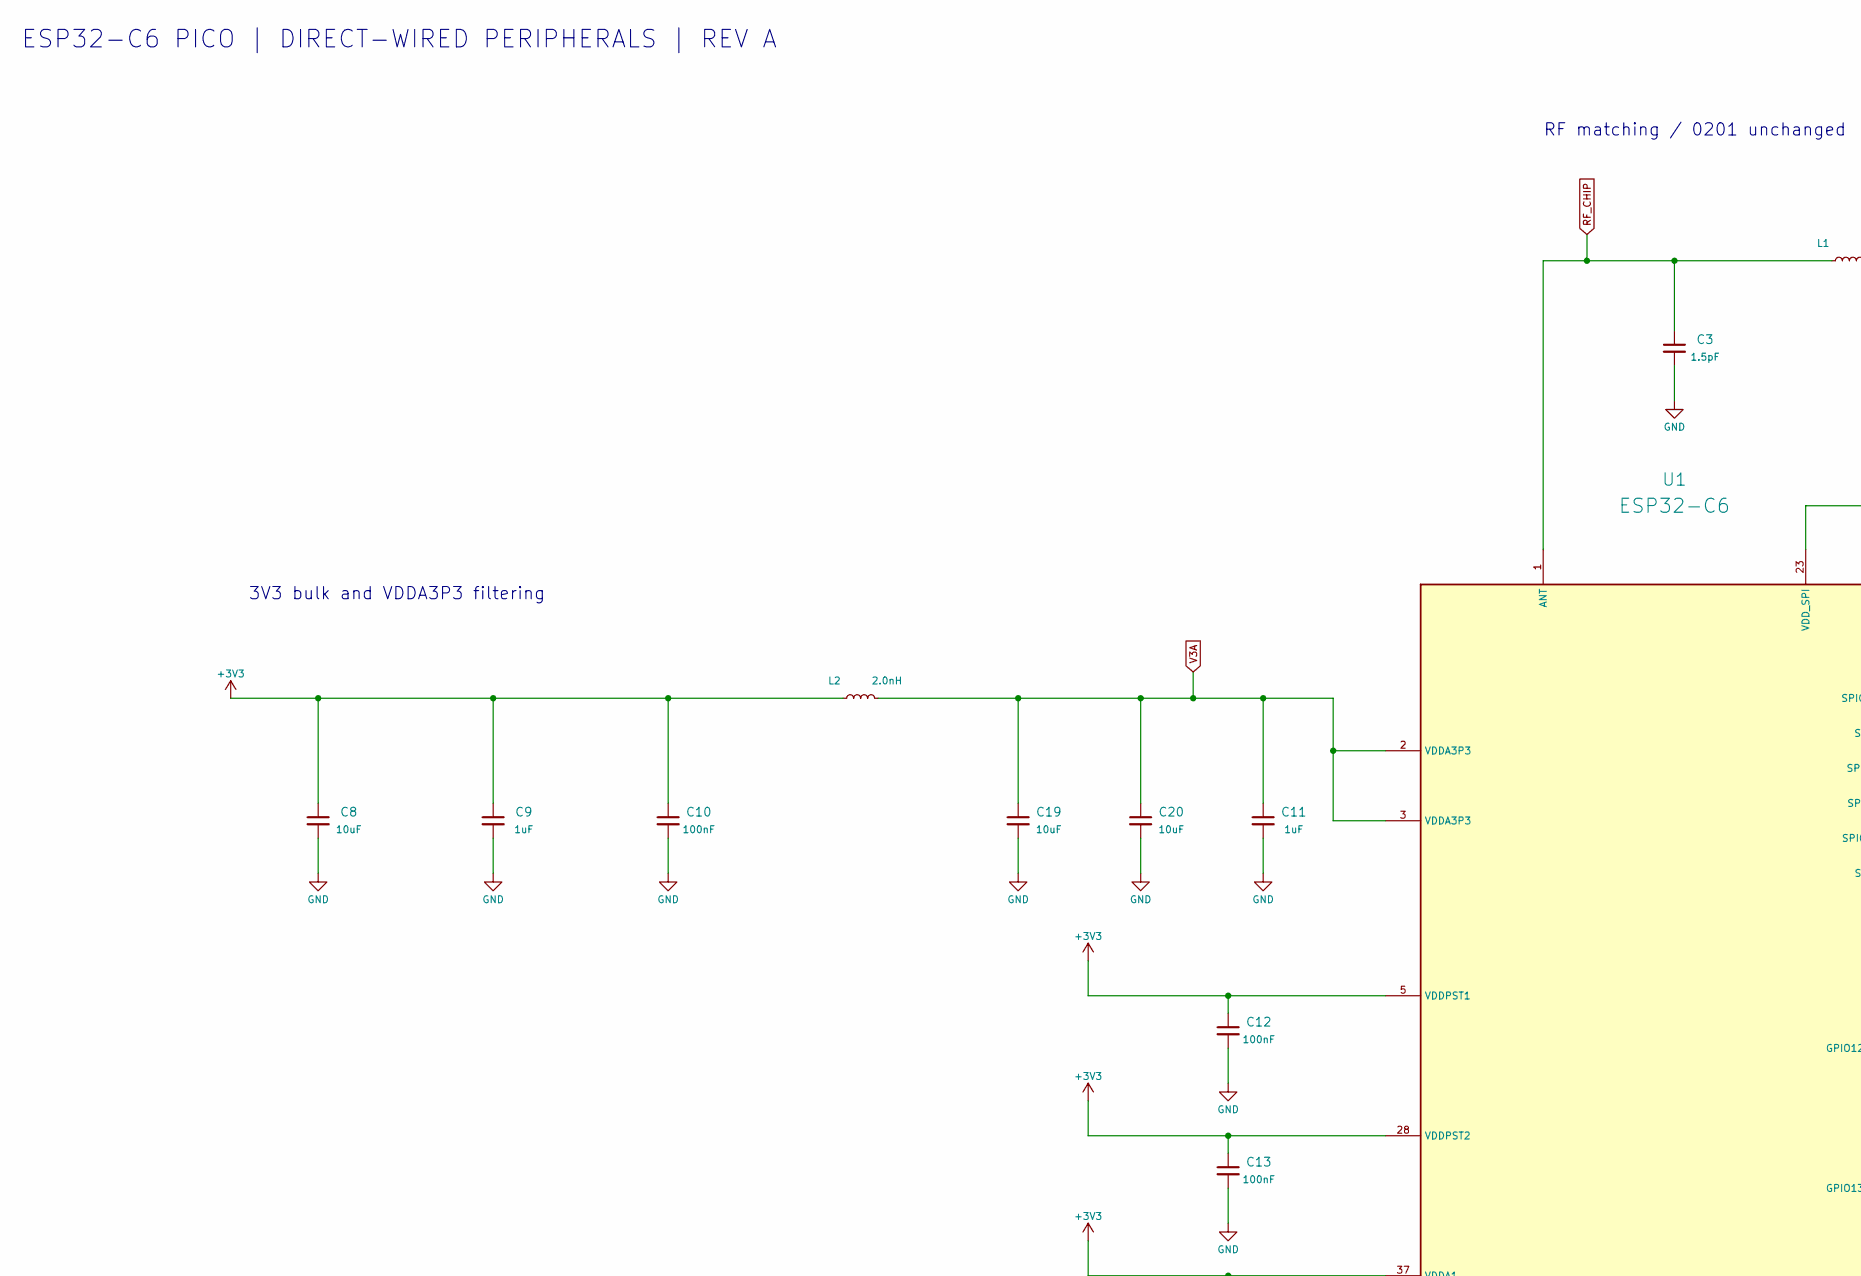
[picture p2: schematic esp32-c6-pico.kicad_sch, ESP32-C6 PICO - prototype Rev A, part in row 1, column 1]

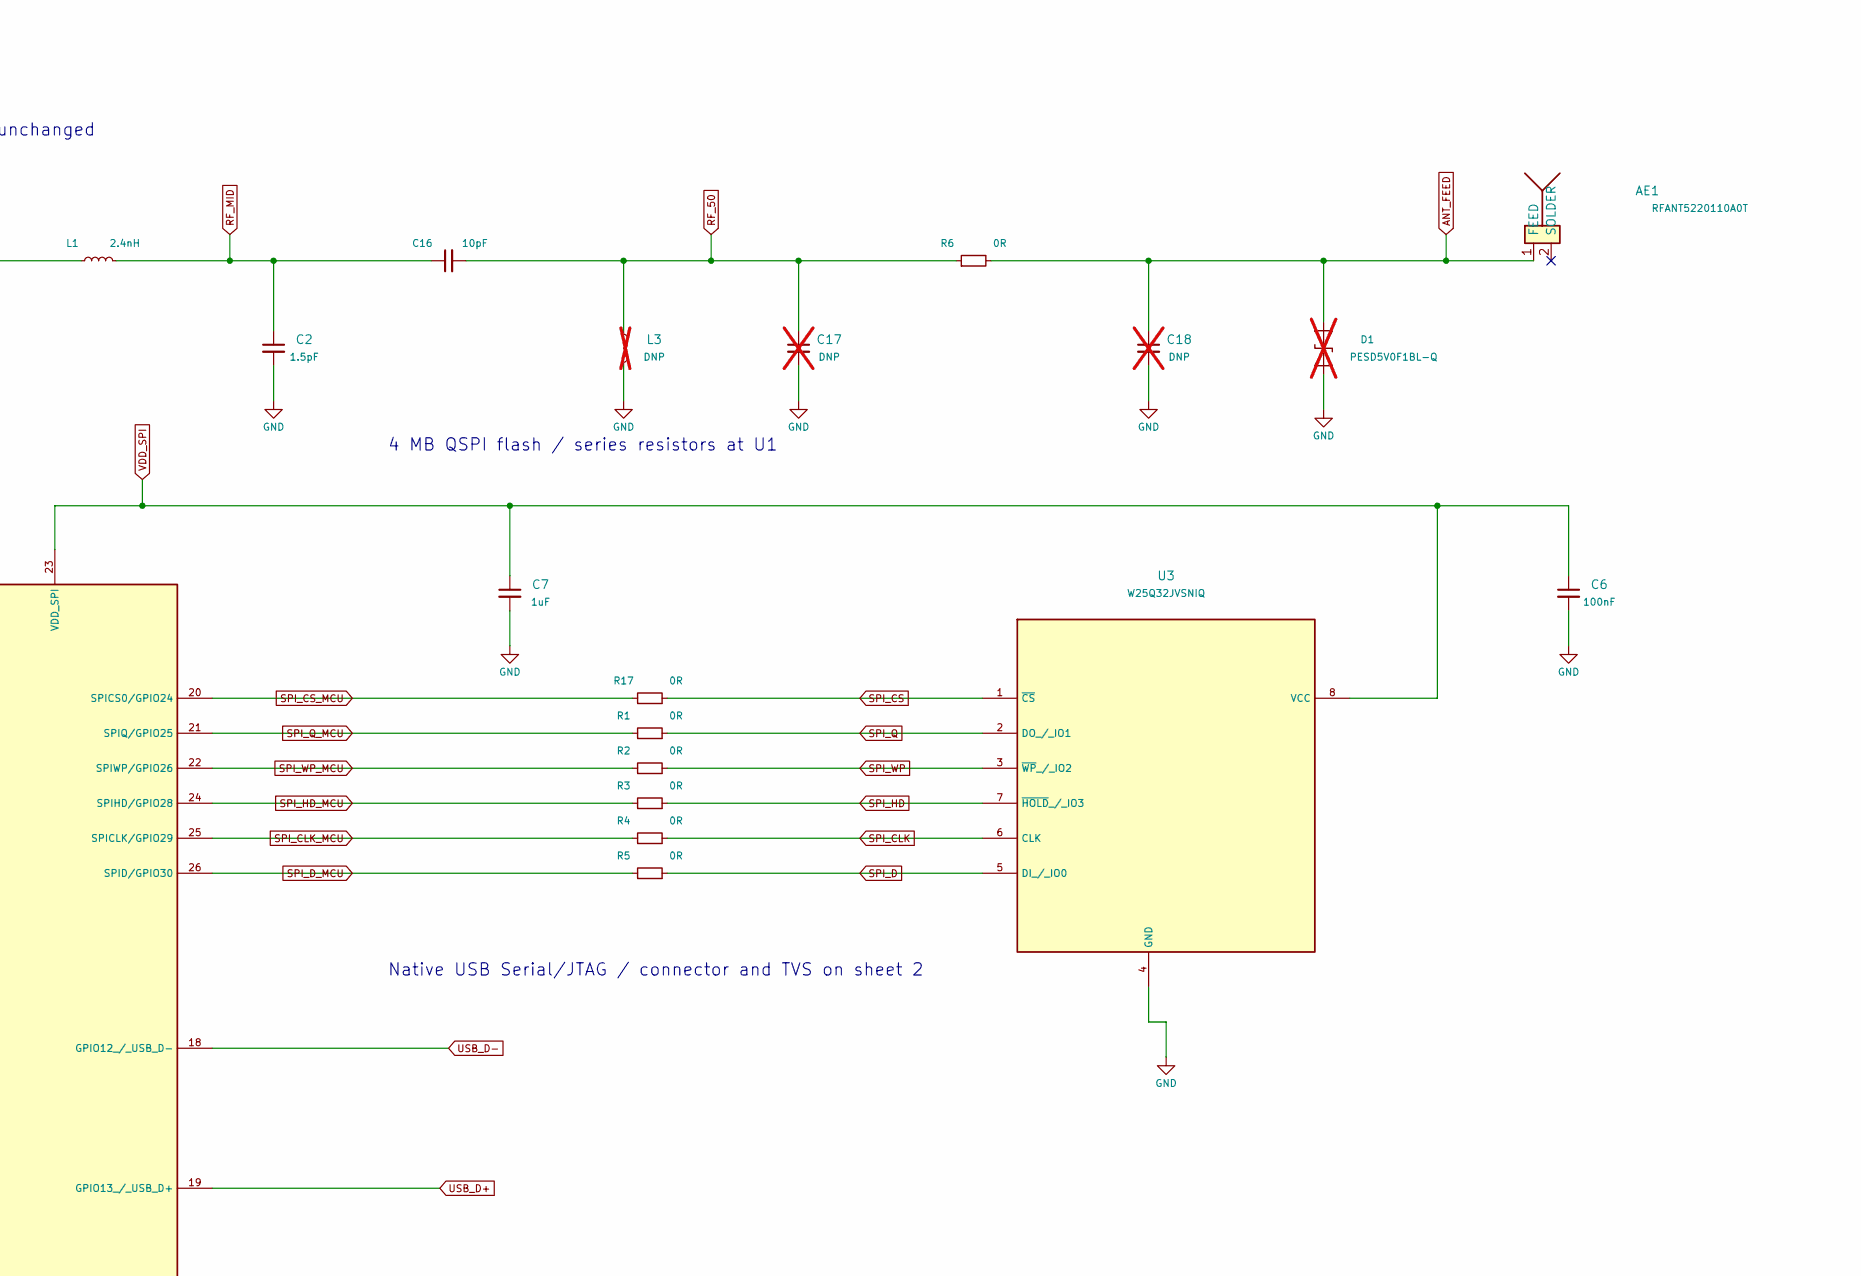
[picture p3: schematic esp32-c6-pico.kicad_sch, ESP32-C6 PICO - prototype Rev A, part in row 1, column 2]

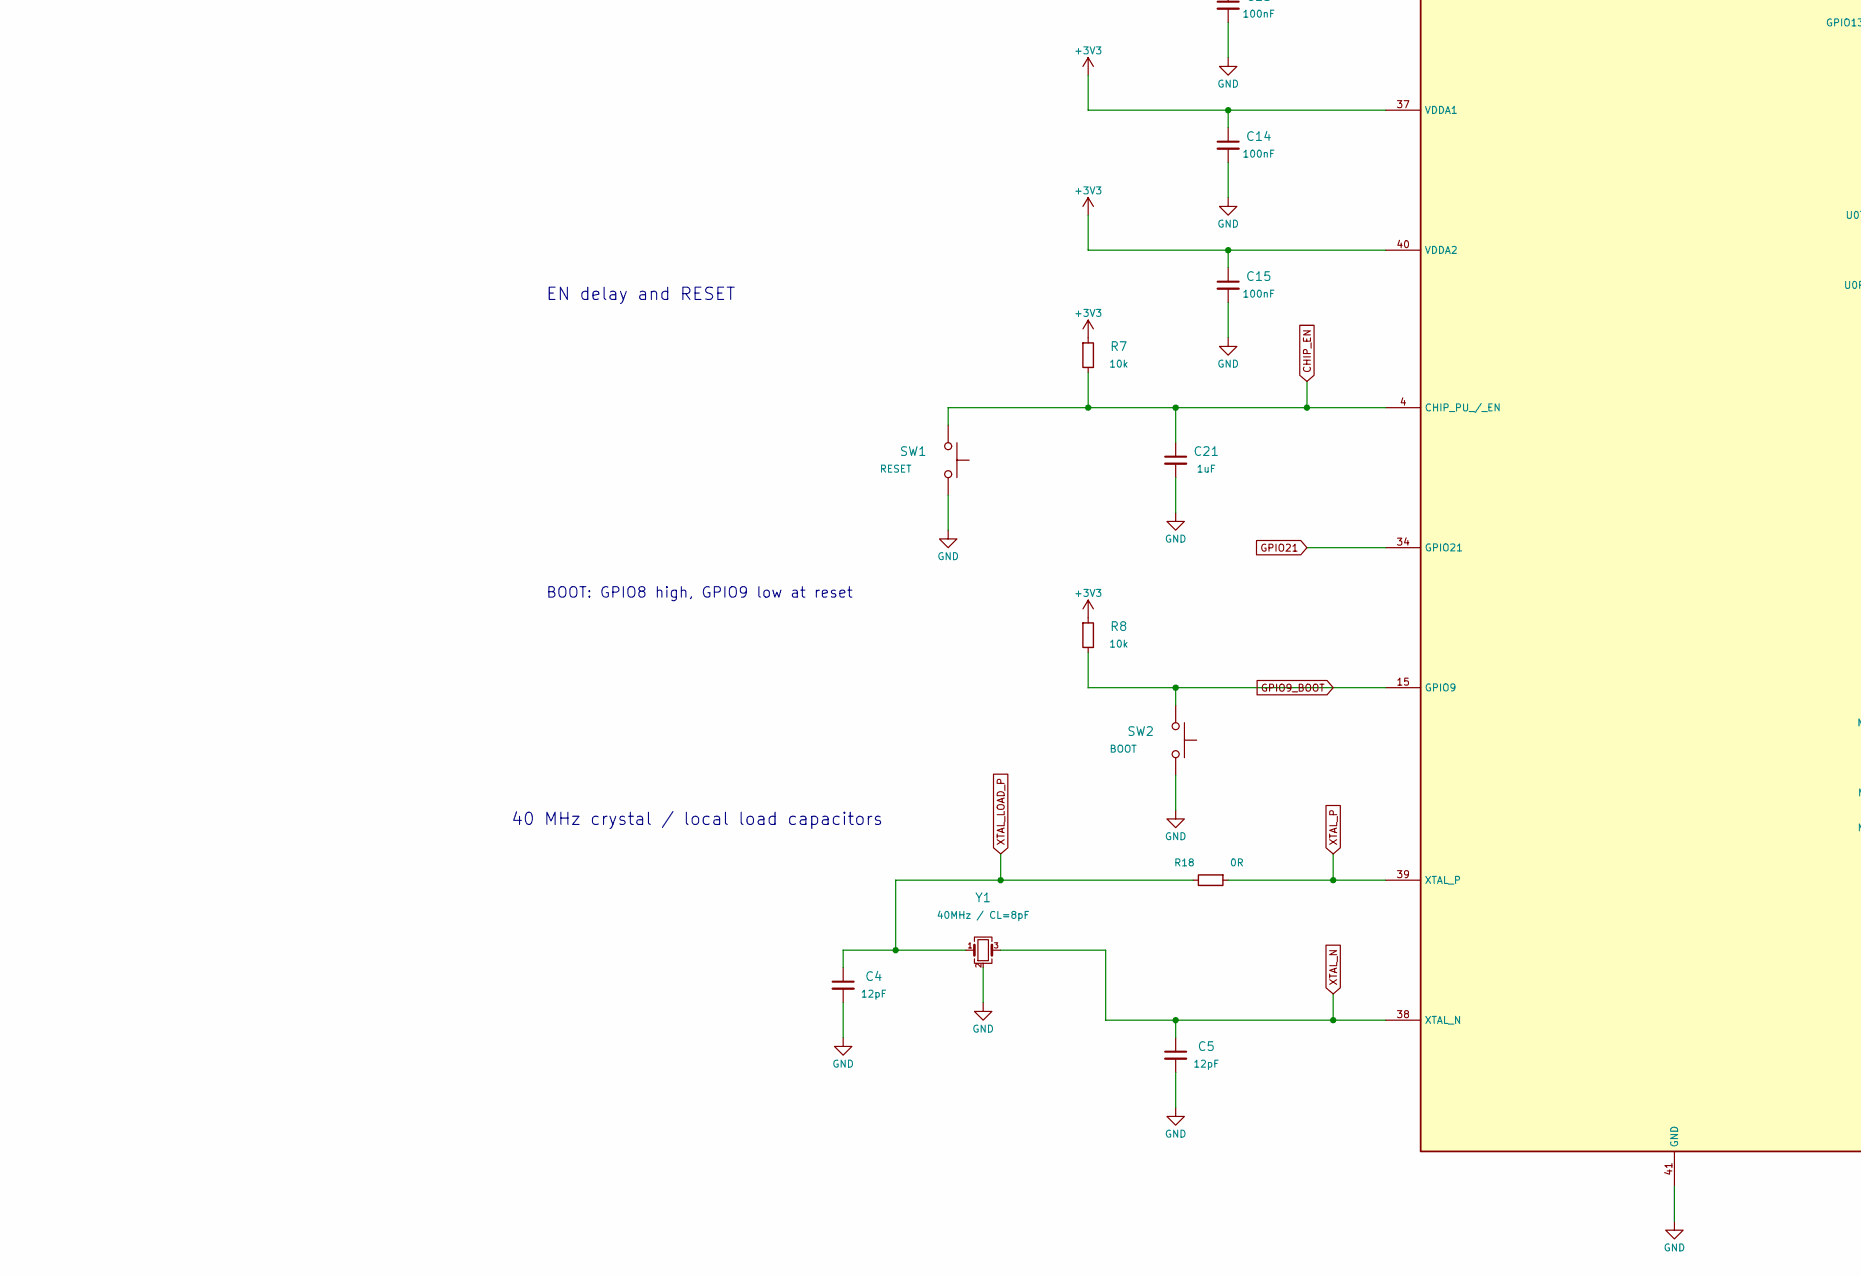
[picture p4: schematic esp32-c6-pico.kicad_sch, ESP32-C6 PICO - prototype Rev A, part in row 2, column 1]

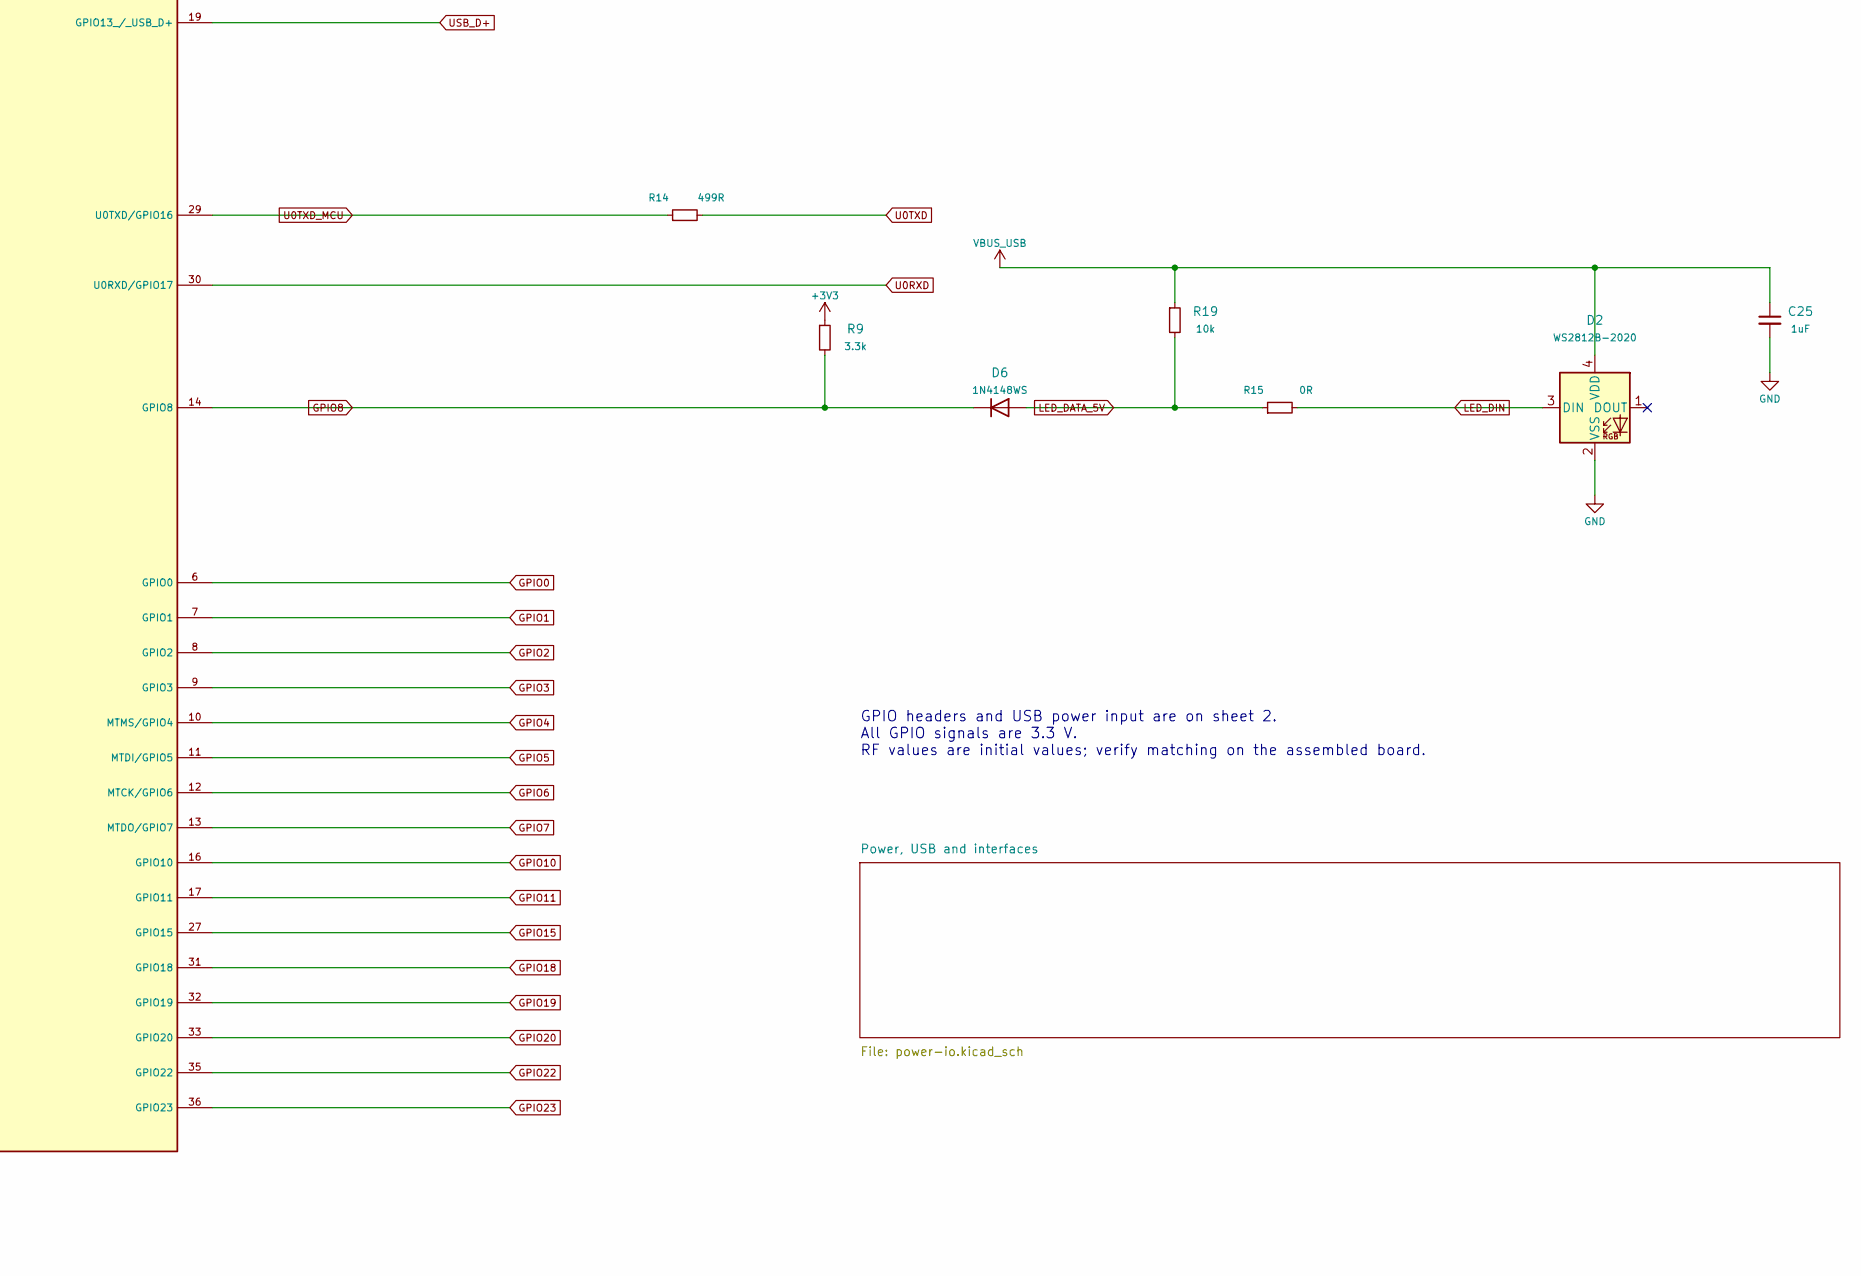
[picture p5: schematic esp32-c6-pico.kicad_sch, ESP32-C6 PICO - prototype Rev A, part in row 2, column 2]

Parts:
AE1: RFANT5220110A0T; MPN RFANT5220110A0T
C2, C3: 1.5pF; C_0201_0603Metric; MPN 1.5pF
C4, C5: 12pF; C_0402_1005Metric; MPN 12pF
C6, C10, C12, C13, C14, C15: 100nF; C_0402_1005Metric; MPN 100nF
C7, C9, C11, C21, C25: 1uF; C_0402_1005Metric; MPN 1uF
C8, C19, C20: 10uF; C_0402_1005Metric; MPN 10uF
C16: 10pF; C_0201_0603Metric; MPN 10pF
C17, C18: DNP; C_0201_0603Metric; MPN DNP; not fitted
D1: PESD5V0F1BL-Q; D_SOD-882; MPN PESD5V0F1BL-Q; not fitted
D2: WS2812B-2020; LED_WS2812B-2020_PLCC4_2.0x2.0mm; MPN WS2812B-2020
D6: 1N4148WS; D_SOD-323; MPN 1N4148WS-7-F
L1: 2.4nH; L_0201_0603Metric; MPN 2.4nH
L2: 2.0nH; L_0402_1005Metric; MPN 2.0nH
L3: DNP; L_0201_0603Metric; MPN DNP; not fitted
R1, R2, R3, R4, R5, R15, R17, R18: 0R; R_0402_1005Metric; MPN 0R
R6: 0R; R_0201_0603Metric; MPN 0R
R7, R8, R19: 10k; R_0402_1005Metric; MPN 10k
R9: 3.3k; R_0402_1005Metric; MPN 3.3k
R14: 499R; R_0402_1005Metric; MPN 499R
SW1: RESET; SW_Push_1P1T_NO_CK_KMR2; MPN KMR221GLFS
SW2: BOOT; SW_Push_1P1T_NO_CK_KMR2; MPN KMR221GLFS
U1: ESP32-C6; QFN40_ESP32_C6_Compact; MPN ESP32-C6
U3: W25Q32JVSNIQ; SOIC-8_3.9x4.9mm_P1.27mm; MPN W25Q32JVSNIQ
Y1: 40MHz / CL=8pF; Crystal_SMD_2016-4Pin_2.0x1.6mm; MPN E9X400081G08

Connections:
+3V3: C8.1, C9.1, C10.1, C12.1, C13.1, C14.1, C15.1, L2.1, R7.1, R8.1, R9.1, U1.5 (VDDPST1), U1.28 (VDDPST2), U1.37 (VDDA1), U1.40 (VDDA2); also elsewhere on the board
ANT_FEED: AE1.1 (FEED_1), C18.1, D1.2 (A2), R6.2
CHIP_EN: C21.1, R7.2, SW1.1, U1.4 (CHIP_PU_/_EN)
GND: C2.2, C3.2, C4.2, C5.2, C6.2, C7.2, C8.2, C9.2, C10.2, C11.2, C12.2, C13.2, C14.2, C15.2, C17.2, C18.2, C19.2, C20.2, C21.2, C25.2, D1.1 (A1), D2.2 (VSS), L3.2, SW1.2, SW2.2, U1.41 (GND), U3.4 (GND), Y1.2 (G), Y1.4 (G); also elsewhere on the board
GPIO0: U1.6 (GPIO0); also elsewhere on the board
GPIO1: U1.7 (GPIO1); also elsewhere on the board
GPIO2: U1.8 (GPIO2); also elsewhere on the board
GPIO3: U1.9 (GPIO3); also elsewhere on the board
GPIO4: U1.10 (MTMS/GPIO4); also elsewhere on the board
GPIO5: U1.11 (MTDI/GPIO5); also elsewhere on the board
GPIO6: U1.12 (MTCK/GPIO6); also elsewhere on the board
GPIO7: U1.13 (MTDO/GPIO7); also elsewhere on the board
GPIO8: D6.1 (K), R9.2, U1.14 (GPIO8)
GPIO9_BOOT: R8.2, SW2.1, U1.15 (GPIO9); also elsewhere on the board
GPIO10: U1.16 (GPIO10); also elsewhere on the board
GPIO11: U1.17 (GPIO11); also elsewhere on the board
GPIO15: U1.27 (GPIO15); also elsewhere on the board
GPIO18: U1.31 (GPIO18); also elsewhere on the board
GPIO19: U1.32 (GPIO19); also elsewhere on the board
GPIO20: U1.33 (GPIO20); also elsewhere on the board
GPIO21: U1.34 (GPIO21); also elsewhere on the board
GPIO22: U1.35 (GPIO22); also elsewhere on the board
GPIO23: U1.36 (GPIO23); also elsewhere on the board
LED_DATA_5V: D6.2 (A), R15.1, R19.2
LED_DIN: D2.3 (DIN), R15.2
RF_50: C16.2, C17.1, L3.1, R6.1
RF_CHIP: C3.1, L1.1, U1.1 (ANT)
RF_MID: C2.1, C16.1, L1.2
SPI_CLK: R4.2, U3.6 (CLK)
SPI_CLK_MCU: R4.1, U1.25 (SPICLK/GPIO29)
SPI_CS: R17.2, U3.1 (~CS)
SPI_CS_MCU: R17.1, U1.20 (SPICS0/GPIO24)
SPI_D: R5.2, U3.5 (DI_/_IO0)
SPI_D_MCU: R5.1, U1.26 (SPID/GPIO30)
SPI_HD: R3.2, U3.7 (~HOLD_/_IO3)
SPI_HD_MCU: R3.1, U1.24 (SPIHD/GPIO28)
SPI_Q: R1.2, U3.2 (DO_/_IO1)
SPI_Q_MCU: R1.1, U1.21 (SPIQ/GPIO25)
SPI_WP: R2.2, U3.3 (~WP_/_IO2)
SPI_WP_MCU: R2.1, U1.22 (SPIWP/GPIO26)
U0RXD: U1.30 (U0RXD/GPIO17); also elsewhere on the board
U0TXD: R14.2; also elsewhere on the board
U0TXD_MCU: R14.1, U1.29 (U0TXD/GPIO16)
USB_D+: U1.19 (GPIO13_/_USB_D+); also elsewhere on the board
USB_D-: U1.18 (GPIO12_/_USB_D-); also elsewhere on the board
V3A: C11.1, C19.1, C20.1, L2.2, U1.2 (VDDA3P3), U1.3 (VDDA3P3)
VBUS_USB: C25.1, D2.4 (VDD), R19.1; also elsewhere on the board
VDD_SPI: C6.1, C7.1, U1.23 (VDD_SPI), U3.8 (VCC)
XTAL_LOAD_P: C4.1, R18.2, Y1.1
XTAL_N: C5.1, U1.38 (XTAL_N), Y1.3
XTAL_P: R18.1, U1.39 (XTAL_P)

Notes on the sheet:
3V3 bulk and VDDA3P3 filtering
Native USB Serial/JTAG / connector and TVS on sheet 2
ESP32-C6 PICO | DIRECT-WIRED PERIPHERALS | REV A
40 MHz crystal / local load capacitors
GPIO headers and USB power input are on sheet 2. All GPIO signals are 3.3 V. RF values are initial values; verify matching on the assembled board.
BOOT: GPIO8 high, GPIO9 low at reset
RF matching / 0201 unchanged
4 MB QSPI flash / series resistors at U1
EN delay and RESET

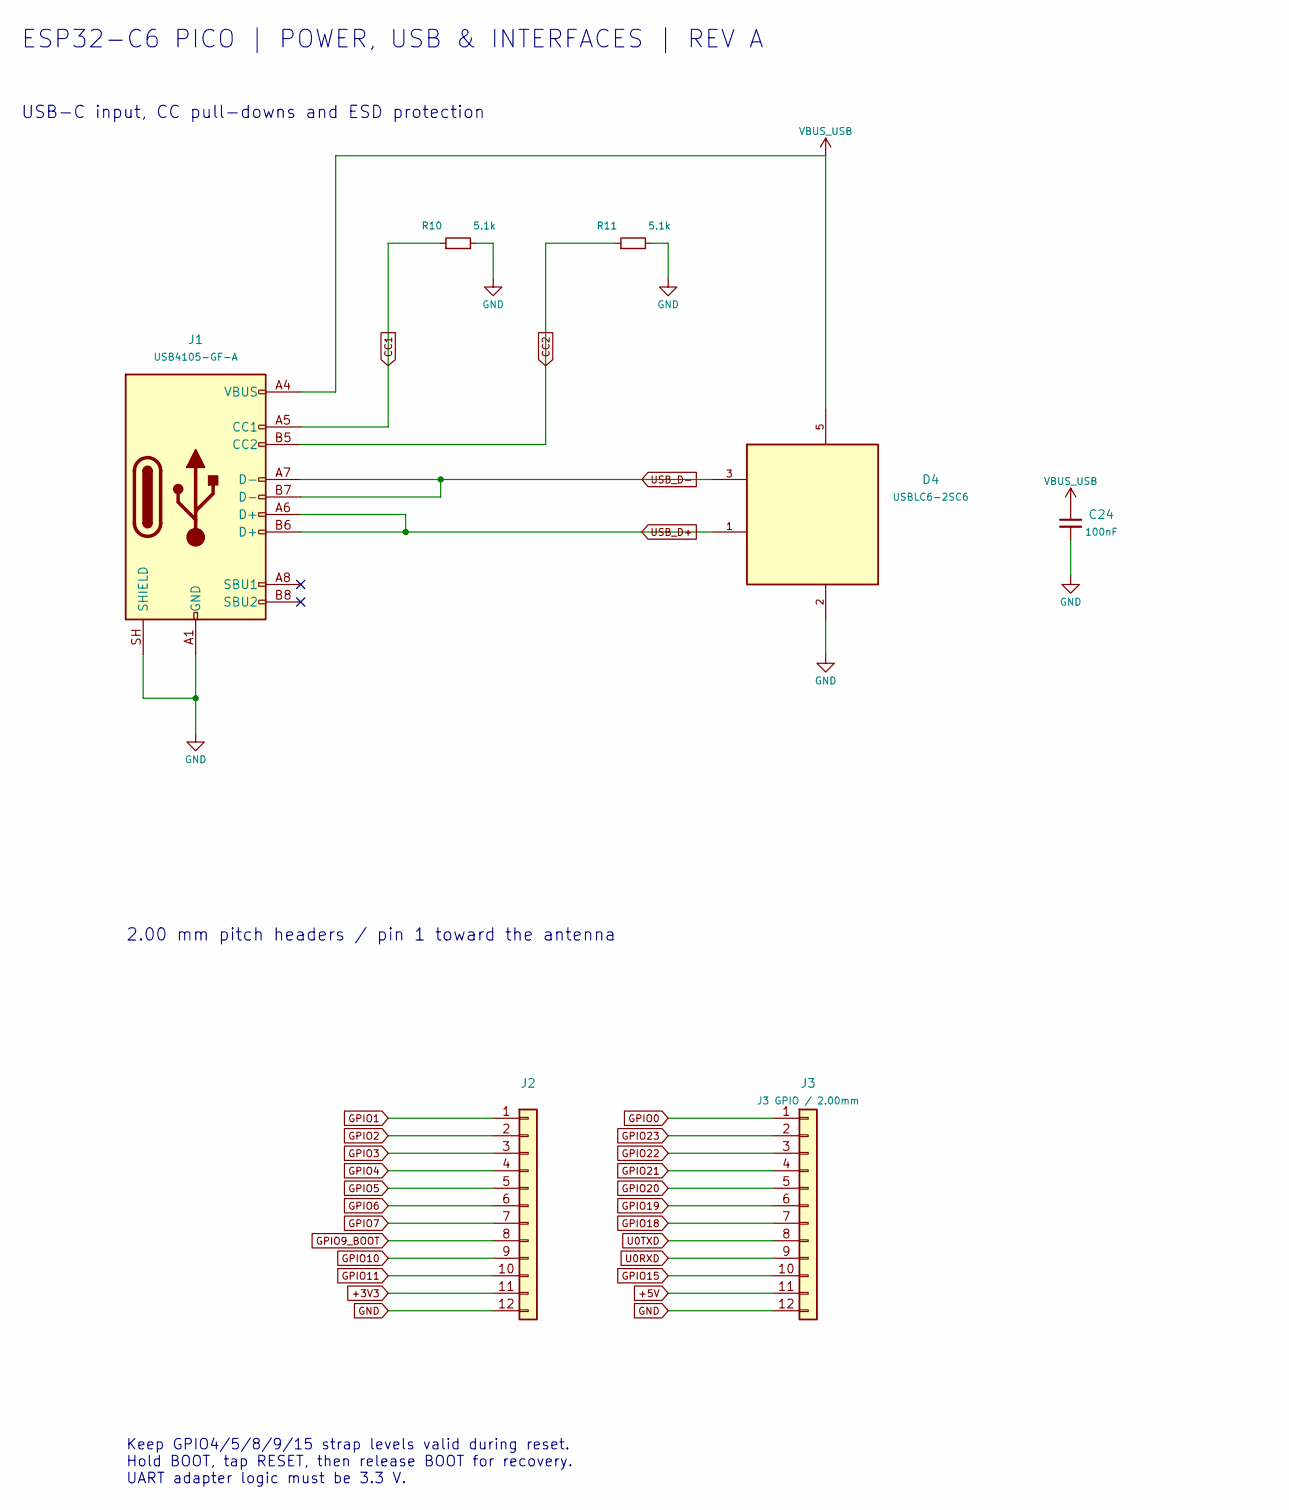
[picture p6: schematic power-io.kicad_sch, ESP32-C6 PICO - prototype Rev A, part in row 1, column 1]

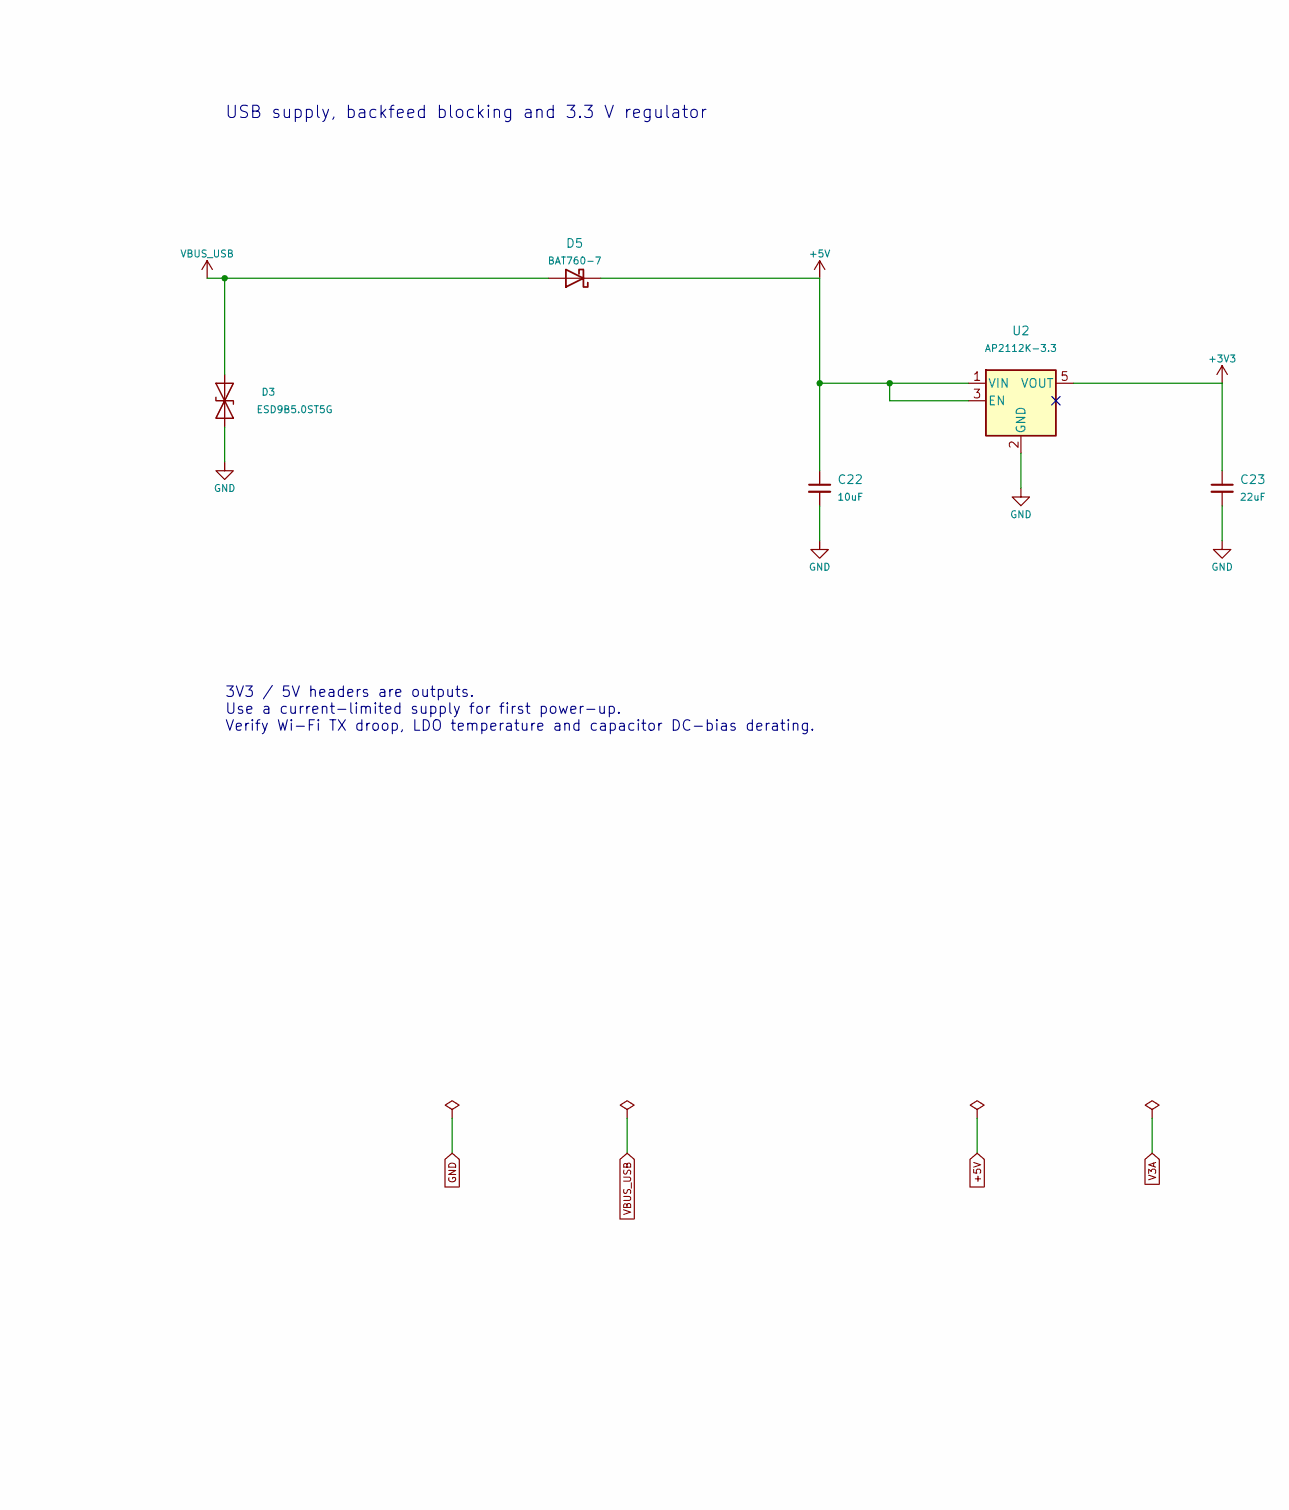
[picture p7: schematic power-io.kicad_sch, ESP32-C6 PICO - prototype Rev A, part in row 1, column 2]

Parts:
C22: 10uF; C_0402_1005Metric; MPN 10uF
C23: 22uF; C_0402_1005Metric; MPN 22uF
C24: 100nF; C_0402_1005Metric; MPN 100nF
D3: ESD9B5.0ST5G; D_SOD-923; MPN ESD9B5.0ST5G
D4: USBLC6-2SC6; SOT-23-6; MPN USBLC6-2SC6
D5: BAT760-7; D_SOD-323; MPN BAT760-7
J1: USB4105-GF-A; USB_C_Receptacle_GCT_USB4105-xx-A_16P_TopMnt_Horizontal; MPN USB4105-GF-A
J2: J2 GPIO / 2.00mm; PinHeader_1x12_P2.00mm_Compact; MPN 1x12 P2.00 vertical header
J3: J3 GPIO / 2.00mm; PinHeader_1x12_P2.00mm_Compact; MPN 1x12 P2.00 vertical header
R10, R11: 5.1k; R_0402_1005Metric; MPN 5.1k
U2: AP2112K-3.3; SOT-23-5; MPN AP2112K-3.3TRG1

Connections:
+3V3: C23.1, J2.11, U2.5 (VOUT); also elsewhere on the board
+5V: C22.1, D5.1 (K), J3.11, U2.1 (VIN), U2.3 (EN)
CC1: J1.A5 (CC1), R10.1
CC2: J1.B5 (CC2), R11.1
GND: C22.2, C23.2, C24.2, D3.1 (A1), D4.2 (GND), J1.A1 (GND), J1.A12 (GND), J1.B1 (GND), J1.B12 (GND), J1.SH (SHIELD), J2.12, J3.12, R10.2, R11.2, U2.2 (GND); also elsewhere on the board
GPIO0: J3.1; also elsewhere on the board
GPIO1: J2.1; also elsewhere on the board
GPIO2: J2.2; also elsewhere on the board
GPIO3: J2.3; also elsewhere on the board
GPIO4: J2.4; also elsewhere on the board
GPIO5: J2.5; also elsewhere on the board
GPIO6: J2.6; also elsewhere on the board
GPIO7: J2.7; also elsewhere on the board
GPIO9_BOOT: J2.8; also elsewhere on the board
GPIO10: J2.9; also elsewhere on the board
GPIO11: J2.10; also elsewhere on the board
GPIO15: J3.10; also elsewhere on the board
GPIO18: J3.7; also elsewhere on the board
GPIO19: J3.6; also elsewhere on the board
GPIO20: J3.5; also elsewhere on the board
GPIO21: J3.4; also elsewhere on the board
GPIO22: J3.3; also elsewhere on the board
GPIO23: J3.2; also elsewhere on the board
U0RXD: J3.9; also elsewhere on the board
U0TXD: J3.8; also elsewhere on the board
USB_D+: D4.1 (D+_(1,6)), D4.6 (D+), J1.A6 (D+), J1.B6 (D+); also elsewhere on the board
USB_D-: D4.3 (D-_(3,4)), D4.4 (D-), J1.A7 (D-), J1.B7 (D-); also elsewhere on the board
VBUS_USB: C24.1, D3.2 (A2), D4.5 (VBUS), D5.2 (A), J1.A4 (VBUS), J1.A9 (VBUS), J1.B4 (VBUS), J1.B9 (VBUS); also elsewhere on the board

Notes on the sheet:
ESP32-C6 PICO | POWER, USB & INTERFACES | REV A
USB-C input, CC pull-downs and ESD protection
3V3 / 5V headers are outputs. Use a current-limited supply for first power-up. Verify Wi-Fi TX droop, LDO temperature and capacitor DC-bias derating.
USB supply, backfeed blocking and 3.3 V regulator
2.00 mm pitch headers / pin 1 toward the antenna
Keep GPIO4/5/8/9/15 strap levels valid during reset. Hold BOOT, tap RESET, then release BOOT for recovery. UART adapter logic must be 3.3 V.

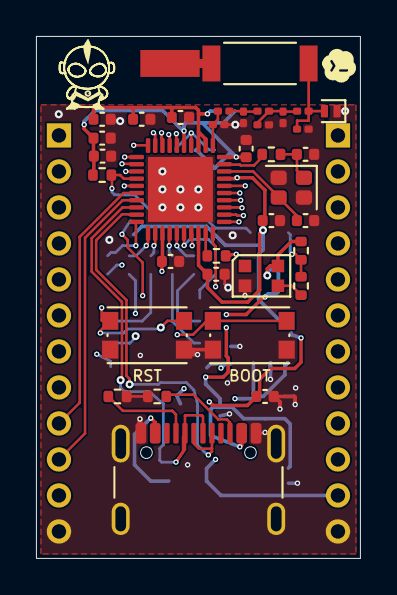
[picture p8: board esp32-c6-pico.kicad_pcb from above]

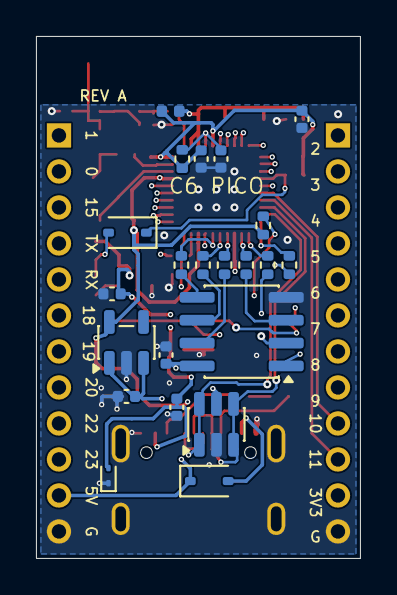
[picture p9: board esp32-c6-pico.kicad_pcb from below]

Board: 4 copper layers, 18.0 x 29.0 mm, 59 parts (24 on the bottom side), 54 nets.

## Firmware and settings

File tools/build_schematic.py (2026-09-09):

"""Generate the completed, portable KiCad schematic and its explicit pin/net map.

Run using the Python shipped with KiCad. Original CAD files are preserved in backups.
All circuit connectivity is declared here; PCB generation consumes KiCad's exported
XML netlist, never a second independently maintained connectivity definition.
"""
from __future__ import annotations

import copy
import csv
import json
import math
import uuid
from pathlib import Path

from kicad_sexpr import Atom as A, child, children, dumps, parse, prop, read, symbol_from_library

if __name__ == '__main__':
    raise SystemExit('Historical generator disabled. Edit the KiCad schematic, or run tools/redraw_schematic.py on a backed-up project and re-export its netlist/ERC.')

ROOT = Path(__file__).resolve().parents[1]
LIB = Path('C:/Program Files/KiCad/10.0/share/kicad/symbols')
BASE = ROOT / 'backups/before-foundation-20260906/esp32-c6-pico.kicad_sch'
ORIGINAL = read(BASE)
OLD_LIBS = {s[1]: s for s in children(child(ORIGINAL, 'lib_symbols'), 'symbol')}
OLD_IDS = {prop(s, 'Reference'): child(s, 'uuid')[1] for s in children(ORIGINAL, 'symbol')}
ROOT_ID = child(ORIGINAL, 'uuid')[1]


def uid(key):
    return str(uuid.uuid5(uuid.UUID(ROOT_ID), key))


def form(text):
    return parse(text)


def grid(value):
    return round(round(value / 1.27) * 1.27, 4)


LIBRARIES = {}
USED = {}
PARTS = []
SHEETS = {'core': [], 'io': []}
SHEET_ID = {'core': ROOT_ID, 'io': uid('power-io-sheet')}
SHEET_INSTANCE = uid('power-io-instance')


def get_symbol(lib_id):
    if lib_id in USED:
        return USED[lib_id]
    if lib_id == 'Pico_Custom:SN74LV1T125':
        library = read(LIB/'74xGxx.kicad_sym')
        sym = symbol_from_library(library, '74AHCT1G125')
        sym[1] = lib_id
        for field in children(sym,'property'):
            if field[1]=='Value':field[2]='SN74LV1T125'
            if field[1]=='Datasheet':field[2]='https://www.ti.com/lit/ds/symlink/sn74lv1t125.pdf'
            if field[1]=='Description':field[2]='Single-supply logic-level translating buffer, active-low OE, 1.6-5.5 V supply'
    elif lib_id in OLD_LIBS:
        sym = copy.deepcopy(OLD_LIBS[lib_id])
    else:
        lib, name = lib_id.split(':')
        if lib not in LIBRARIES:
            LIBRARIES[lib] = read(LIB / (lib + '.kicad_sym'))
        sym = symbol_from_library(LIBRARIES[lib], name)
        sym[1] = lib_id
    # Ship a local copy of every used symbol, removing reliance on add-ons.
    if lib_id == 'espressif-kicad-addon:ESP32-C6':
        for unit in children(sym, 'symbol'):
            for pin in children(unit, 'pin'):
                if child(pin, 'number')[1] == '23':
                    pin[1] = A('power_out')
                    child(pin, 'name')[1] = 'VDD_SPI'
    USED[lib_id] = sym
    return sym


def note(sheet, text, x, y, size=1.27):
    SHEETS[sheet].append(form(f'(text {json.dumps(text)} (at {grid(x)} {grid(y)} 0) '
                              f'(effects (font (size {size} {size})) (justify left bottom)) '
                              f'(uuid "{uid(sheet+text)}"))'))


def wire(sheet, p, q, key):
    if p == q:
        return
    SHEETS[sheet].append(form(f'(wire (pts (xy {p[0]} {p[1]}) (xy {q[0]} {q[1]})) '
                              f'(stroke (width 0) (type default)) (uuid "{uid(key)}"))'))


def label(sheet, net, x, y, angle, key):
    # Net names are global because the supply / interfaces occupy a second sheet.
    justification = 'left' if angle in (0, 90) else 'right'
    SHEETS[sheet].append(form(f'(global_label {json.dumps(net)} (shape input) '
                              f'(at {x} {y} {angle}) (effects (font (size 0.9 0.9)) '
                              f'(justify {justification})) (uuid "{uid(key)}") '
                              f'(property "Intersheetrefs" "${{INTERSHEET_REFS}}" '
                              f'(at {x} {y} {angle}) (effects (font (size 1 1)) (hide yes))))'))


def part(ref, lib_id, value, footprint, nets, x, y, angle=0, sheet='core', dnp=False, mpn='', detail='', datasheet=None):
    sym = get_symbol(lib_id)
    x, y = grid(x), grid(y)
    path = '/' + ROOT_ID + ('/' + SHEET_INSTANCE if sheet == 'io' else '')
    instance_id = OLD_IDS.get(ref, uid(ref))
    pins = [p for u in children(sym, 'symbol') for p in children(u, 'pin')]
    nets = {str(k): v for k, v in nets.items()}
    assert {child(p, 'number')[1] for p in pins} == set(nets), (ref, nets)
    local_name = lib_id.replace(':', '__')
    # Every instance uses a shipped library with a stable definition.
    instance = form(f'(symbol (lib_id "Pico_Design:{local_name}") (at {x} {y} {angle}) '
                    f'(unit 1) (in_bom {"no" if ref.startswith("#") else "yes"}) '
                    f'(on_board {"no" if ref.startswith("#") else "yes"}) '
                    f'(dnp {"yes" if dnp else "no"}) (uuid "{instance_id}"))')
    # Passives get labels alongside their bodies; ICs above their outlines.
    if len(pins) <= 2:
        positions = [(x + 2.54, y - 1.27), (x + 2.54, y + 1.27)] if angle == 0 else [(x, y - 3.81), (x, y + 3.81)]
    else:
        ymax = max(float(child(p, 'at')[2]) for p in pins)
        positions = [(x, y - ymax - 6.35), (x, y - ymax - 3.81)]
    for i, (name, val) in enumerate([('Reference', ref), ('Value', value), ('Footprint', footprint),
                                    ('Datasheet', datasheet or prop(sym, 'Datasheet')), ('MPN', mpn or value), ('AssemblyNote', detail)]):
        px, py = positions[i] if i < 2 else (x, y)
        hidden = i >= 2 or ref.startswith('#')
        instance.append(form(f'(property {json.dumps(name)} {json.dumps(val)} (at {px} {py} 0) '
                             f'(effects (font (size {1.0 if i==0 else 0.9} {1.0 if i==0 else 0.9})) '
                             f'{"(hide yes)" if hidden else ""}))'))
    seen = set()
    for pin in pins:
        num = child(pin, 'number')[1]
        instance.append(form(f'(pin "{num}" (uuid "{uid(ref+"/"+num)}"))'))
        px, py, pa = map(float, child(pin, 'at')[1:4])
        rad = math.radians(angle)
        rx, ry = px*math.cos(rad)-py*math.sin(rad), px*math.sin(rad)+py*math.cos(rad)
        end = (round(x+rx, 4), round(y-ry, 4))
        if end in seen:
            continue
        seen.add(end)
        net = nets[num]
        if net is None:
            SHEETS[sheet].append(form(f'(no_connect (at {end[0]} {end[1]}) (uuid "{uid(ref+num+"nc")}"))'))
            continue
        direction = (pa + angle) % 360
        # Extend away from the component, then attach the global label facing inward.
        er = math.radians(direction)
        outer = (round(end[0] - 2.54*math.cos(er), 4), round(end[1] + 2.54*math.sin(er), 4))
        wire(sheet, end, outer, ref+num+'wire')
        label(sheet, net, *outer, int((direction + 180) % 360), ref+num+'label')
    instance.append(form(f'(instances (project "esp32-c6-pico" '
                         f'(path "{path}" (reference "{ref}") (unit 1))))'))
    SHEETS[sheet].append(instance)
    if not ref.startswith('#'):
        PARTS.append(dict(ref=ref, value=value, footprint=footprint, nets=nets, uuid=instance_id,
                          sheet=sheet, path=path+'/'+instance_id, dnp=dnp, mpn=mpn or value, note=detail))


C0402 = 'Capacitor_SMD:C_0402_1005Metric'
C0201 = 'Capacitor_SMD:C_0201_0603Metric'
C0603 = 'Capacitor_SMD:C_0603_1608Metric'
R0402 = 'Resistor_SMD:R_0402_1005Metric'
R0201 = 'Resistor_SMD:R_0201_0603Metric'
L0201 = 'Inductor_SMD:L_0201_0603Metric'


def passive(ref, value, net1, net2, x, y, sheet='core', angle=0, fp=None, dnp=False, note=''):
    kind = ref[0]
    default = {'C': C0402, 'R': R0402, 'L': L0201}[kind]
    part(ref, 'Device:'+kind+'_Small', value, fp or default, {1: net1, 2: net2},
         x, y, angle, sheet, dnp, detail=note)


def build():
    note('core', 'ESP32-C6 PICO | CORE, RF & FLASH | REV A', 20, 20, 2.54)
    note('core', '01  ESP32-C6 QFN40 - external 4 MB flash', 20, 42, 1.8)
    main = {1:'RF_CHIP',2:'V3A',3:'V3A',4:'CHIP_EN',5:'+3V3',6:'GPIO0',7:'GPIO1',8:'GPIO2',9:'GPIO3',
            10:'GPIO4',11:'GPIO5',12:'GPIO6',13:'GPIO7',14:'GPIO8',15:'GPIO9_BOOT',16:'GPIO10',17:'GPIO11',
            18:'USB_MCU_D-',19:'USB_MCU_D+',20:'SPI_CS_MCU',21:'SPI_Q_MCU',22:'SPI_WP_MCU',23:'VDD_SPI',
            24:'SPI_HD_MCU',25:'SPI_CLK_MCU',26:'SPI_D_MCU',27:'GPIO15',28:'+3V3',29:'U0TXD_MCU',30:'U0RXD',
            31:'GPIO18',32:'GPIO19',33:'GPIO20',34:'GPIO21_LED',35:'GPIO22',36:'GPIO23',37:'+3V3',38:'XTAL_N',39:'XTAL_P',40:'+3V3',41:'GND'}
    part('U1','espressif-kicad-addon:ESP32-C6','ESP32-C6',
         'Pico:QFN40_ESP32_C6_Compact',main,88.9,105.41,detail='QFN40, NOT the pin-incompatible C6FH4 QFN32')
    note('core', '02  RF chip CLCCL filter + antenna pi network', 162, 42, 1.8)
    passive('C3','1.5pF','RF_CHIP','GND',172,65,fp=C0201,note='C0G; RF initial value, VNA tuning required')
    passive('L1','2.4nH','RF_CHIP','RF_MID',191,55,angle=90,note='High-Q RF; initial value')
    passive('C2','1.5pF','RF_MID','GND',210,65,fp=C0201,note='C0G; RF initial value')
    passive('C16','10pF','RF_MID','RF_50',229,55,angle=90,fp=C0201,note='C0G DC-block / tuning initial value')
    passive('L3','DNP','RF_50','GND',248,65,dnp=True,note='Shunt RF tuning option')
    passive('C17','DNP','RF_50','GND',273,65,fp=C0201,dnp=True,note='Antenna pi input shunt')
    passive('R6','0R','RF_50','ANT_FEED',292,55,angle=90,fp=R0201,note='Antenna pi series tuning option')
    passive('C18','DNP','ANT_FEED','GND',312,65,fp=C0201,dnp=True,note='Antenna pi output shunt')
    part('AE1','Walsin_Antenna:RFANT5220110A0T','RFANT5220110A0T',
         'Walsin_Antenna:RFANT5220110A0T',{1:'ANT_FEED',2:None},360,54,
         detail='Pad 2 stays open with axial end copper; horizontal prototype, 20.5x3.5 mm all-layer clearance; RF validation required')
    part('D1','Diode:ESD9B5.0ST5G','PESD5V0F1BL-Q','Diode_SMD:D_SOD-882',
         {1:'GND',2:'ANT_FEED'},341,77,90,dnp=True,detail='0.4 pF antenna ESD option; original 15 pF ESD9B is unsuitable',
         datasheet='https://assets.nexperia.com/documents/data-sheet/PESD5V0F1BL-Q.pdf')
    note('core','RF values are starting points only. Tune with the assembled PCB and final enclosure.\n0201 RF filter; 50 ohm feed referenced to L2 GND. Keep all layers clear in antenna area.',163,92)
    note('core','03  Power decoupling - fit at the named pins',162,111,1.8)
    caps = [('C8','10uF','+3V3',C0402,'Main bulk'),('C9','1uF','+3V3',C0402,'Main bulk'),
            ('C10','100nF','+3V3',C0402,'Main HF'),('C12','100nF','+3V3',C0402,'U1 pin 5'),
            ('C13','100nF','+3V3',C0402,'U1 pin 28'),('C14','100nF','+3V3',C0402,'U1 pin 37'),
            ('C15','100nF','+3V3',C0402,'U1 pin 40')]
    for i,(ref,val,net,fp,msg) in enumerate(caps):
        passive(ref,val,net,'GND',171+i*30,132,fp=fp,note=msg+'; X7R 10 V minimum')
    passive('L2','2.0nH','+3V3','V3A',177,166,angle=90,fp='Inductor_SMD:L_0402_1005Metric',note='RF supply filter; Irated >= 500 mA, low DCR')
    passive('C11','1uF','V3A','GND',214,166,note='U1 pins 2/3 local bypass')
    passive('C19','10uF','V3A','GND',246,166,fp=C0402,note='U1 pin 2 local bulk')
    passive('C20','10uF','V3A','GND',278,166,fp=C0402,note='U1 pin 3 local bulk')
    note('core','04  Quad-SPI flash, powered from U1 VDD_SPI',20,158,1.8)
    flashnets={1:'SPI_CS',2:'SPI_Q',3:'SPI_WP',4:'GND',5:'SPI_D',6:'SPI_CLK',7:'SPI_HD',8:'VDD_SPI'}
    flashnets[9]='GND'
    part('U3','Memory_Flash:W25Q32JVZP','W25Q32JVZPIQ','Package_SON:WSON-8-1EP_6x5mm_P1.27mm_EP3.4x4mm',flashnets,106.68,209.55)
    for i,(ref,key) in enumerate([('R17','CS'),('R1','Q'),('R2','WP'),('R3','HD'),('R4','CLK'),('R5','D')]):
        passive(ref,'0R','SPI_'+key+'_MCU','SPI_'+key,44,178+i*13,angle=90,fp=R0402,note='Place at U1; SPI clock defaults to 40 MHz for bring-up')
    passive('C6','100nF','VDD_SPI','GND',127,198,note='At flash VCC')
    passive('C7','1uF','VDD_SPI','GND',147,198,note='At U1 VDD_SPI pin')
    note('core','05  40 MHz crystal',170,199,1.8)
    passive('R18','0R','XTAL_P','XTAL_LOAD_P',181,219,angle=90,fp='Resistor_SMD:R_0402_1005Metric',note='Crystal series link; 0R per ESP32-C6-WROOM-1/1U v1.4 figs 8-1/8-2 (R4); former L4')
    part('Y1','Device:Crystal_GND24_Small','40MHz / CL=8pF','Crystal:Crystal_SMD_2016-4Pin_2.0x1.6mm',
         {1:'XTAL_LOAD_P',2:'GND',3:'XTAL_N',4:'GND'},227,219,mpn='E9X400081G08',
         detail='Eaton E9X; 40 MHz, CL 8 pF, initial tolerance 10 ppm, ESR <=50 ohm; verify assembled frequency',
         datasheet='https://www.eaton.com/content/dam/eaton/products/electronic-components/resources/data-sheet/eaton-e9x-crystal-resonator-mhz-data-sheet-elx1389-en.pdf')
    passive('C4','12pF','XTAL_LOAD_P','GND',201,244,note='C0G; assumes about 2 pF stray; trim frequency on hardware')
    passive('C5','12pF','XTAL_N','GND',253,244,note='C0G; crystal load tuning')
    note('core','All GPIO signals are 3.3 V only.\nGPIO4/5/8/9/15 are strapping pins.\nDo not force strap levels during reset.\nGPIO21 drives the RGB LED.',293,203)
    # The sheet is referenced here; named global nets connect both sheets.
    SHEETS['core'].append(form(f'(sheet (at 298.45 220.98) (size 78.74 25.4) '
                              f'(stroke (width 0.1524) (type default)) (fill (color 0 0 0 0)) '
                              f'(uuid "{SHEET_INSTANCE}") '
                              f'(property "Sheetname" "Power, USB and interfaces" (at 298.45 219.71 0) (effects (font (size 1.27 1.27)) (justify left bottom))) '
                              f'(property "Sheetfile" "power-io.kicad_sch" (at 298.45 247.65 0) (effects (font (size 1.27 1.27)) (justify left top))) '
                              f'(instances (project "esp32-c6-pico" (path "/{ROOT_ID}" (page "2")))))'))

    note('io','ESP32-C6 PICO | POWER, USB & INTERFACES | REV A',20,20,2.54)
    note('io','06  USB-C native USB Serial/JTAG',20,39,1.8)
    usb={p:'VBUS_USB' for p in ['A4','A9','B4','B9']}
    usb.update({p:'GND' for p in ['A1','A12','B1','B12','SH']})
    usb.update(A5='CC1',B5='CC2',A6='USB_D+',B6='USB_D+',A7='USB_D-',B7='USB_D-',A8=None,B8=None)
    part('J1','Connector:USB_C_Receptacle_USB2.0_16P','USB4105-GF-A',
         'Connector_USB:USB_C_Receptacle_GCT_USB4105-xx-A_16P_TopMnt_Horizontal',usb,40,83,sheet='io')
    passive('R10','5.1k','CC1','GND',80,56,sheet='io',note='1%; one Rd per CC pin')
    passive('R11','5.1k','CC2','GND',104,56,sheet='io',note='1%; USB-C sink, no PD')
    part('D4','Power_Protection:USBLC6-2SC6','USBLC6-2SC6','Package_TO_SOT_SMD:SOT-23-6',
         {1:'USB_D+',2:'GND',3:'USB_D-',4:'USB_D-',5:'VBUS_USB',6:'USB_D+'},103,93,sheet='io')
    passive('R12','22R','USB_D-','USB_MCU_D-',150,81,angle=90,sheet='io')
    passive('R13','22R','USB_D+','USB_MCU_D+',150,102,angle=90,sheet='io')
    passive('C27','DNP','USB_MCU_D-','GND',187,81,sheet='io',dnp=True,note='EMI tuning option; leave open')
    passive('C28','DNP','USB_MCU_D+','GND',210,102,sheet='io',dnp=True,note='EMI tuning option; leave open')
    note('io','D- = GPIO12; D+ = GPIO13.\nUse BOOT + RESET for recovery.\n90 ohm differential routing; 22R at U1.',20,124)

    note('io','07  USB 5 V to 3.3 V supply',237,39,1.8)
    part('F1','Device:Polyfuse_Small','0.75A hold','Fuse:Fuse_1206_3216Metric',
         {1:'VBUS_USB',2:'VBUS_FUSED'},246,57,90,'io',mpn='1206L075/6',detail='Check thermal derating; input source >=500 mA')
    part('D3','Diode:ESD9B5.0ST5G','ESD9B5.0ST5G','Diode_SMD:D_SOD-923',
         {1:'GND',2:'VBUS_USB'},244,82,90,'io',detail='Move original 15 pF TVS to USB power rail')
    part('D5','Device:D_Schottky','SS14FL','Diode_SMD:D_SOD-123F',
         {1:'+5V',2:'VBUS_FUSED'},279,57,180,'io',detail='Blocks USB backfeed; +5V is about VBUS minus diode drop',
         datasheet='https://www.onsemi.com/download/data-sheet/pdf/ss14fl-d.pdf')
    part('U2','Regulator_Linear:AP2112K-3.3','AP2112K-3.3','Package_TO_SOT_SMD:SOT-23-5',
         {1:'+5V',2:'GND',3:'+5V',4:None,5:'+3V3'},331,77,sheet='io',mpn='AP2112K-3.3TRG1',
         detail='600 mA peak rating; continuous load limited by SOT25 dissipation')
    passive('C22','10uF','+5V','GND',282,92,sheet='io',fp=C0402,note='10 V X7R; regulator input')
    passive('C23','22uF','+3V3','GND',374,82,sheet='io',fp=C0402,note='10 V X5R/X7R; verify DC-bias effective capacitance')
    passive('C24','100nF','VBUS_USB','GND',375,113,sheet='io')
    note('io','USB supplies the board. 3V3 / 5V headers are outputs.\nDo not power 3V3 externally while USB is attached.\nRegulator current rating is NOT an external load budget.\nValidate 3V3 droop and LDO temperature during Wi-Fi TX.',235,139)

    note('io','08  Reset, boot and UART recovery',20,152,1.8)
    passive('R7','10k','+3V3','CHIP_EN',28,174,sheet='io')
    passive('C21','1uF','CHIP_EN','GND',54,174,sheet='io')
    part('SW1','Switch:SW_Push','RESET','Button_Switch_SMD:SW_Push_1P1T_NO_CK_KMR2',
         {1:'CHIP_EN',2:'GND'},86,180,sheet='io',mpn='KMR221GLFS')
    passive('R8','10k','+3V3','GPIO9_BOOT',119,174,sheet='io')
    part('SW2','Switch:SW_Push','BOOT','Button_Switch_SMD:SW_Push_1P1T_NO_CK_KMR2',
         {1:'GPIO9_BOOT',2:'GND'},151,180,sheet='io',mpn='KMR221GLFS')
    passive('R9','10k','+3V3','GPIO8',188,174,sheet='io')
    passive('R14','499R','U0TXD_MCU','U0TXD',71,207,angle=90,sheet='io',note='UART0 harmonic damping at U1')
    note('io','Download strap: GPIO8=1, GPIO9=0.\nHold BOOT, tap RESET, release BOOT.\nUART adapter: 3.3 V logic only; TX/RX cross-connect.',20,237)

    note('io','09  2 mm pitch GPIO headers',242,155,1.8)
    left=['GND','+3V3','GPIO0','GPIO1','GPIO2','GPIO3','GPIO4','GPIO5','GPIO6','GPIO7','GPIO8','GPIO9_BOOT']
    right=['+5V','GND','GPIO10','GPIO11','GPIO15','U0TXD','U0RXD','GPIO18','GPIO19','GPIO20','GPIO22','GPIO23']
    for ref,nets,x in [('J2',left,274),('J3',right,371)]:
        part(ref,'Connector_Generic:Conn_01x12',ref+' GPIO / 2.00mm',
             'Pico:PinHeader_1x12_P2.00mm_Compact',
             {str(i+1): n for i,n in enumerate(nets)},x,196,sheet='io',mpn='1x12 P2.00 vertical header')

    note('io','10  RGB indicator - 5 V logic buffer',20,260,1.8)
    # Use a third sheet-sized row on A3; enough horizontal spacing for buffer symbol.
    part('U4','Pico_Custom:SN74LV1T125','SN74LV1T125','Package_TO_SOT_SMD:SOT-23-5',
         {1:'GND',2:'GPIO21_LED',3:'GND',4:'LED_DATA_5V',5:'VBUS_USB'},89,278,sheet='io',mpn='SN74LV1T125DBVR')
    passive('R16','100k','GPIO21_LED','GND',37,279,sheet='io',note='Keep LED data low at reset')
    passive('R15','330R','LED_DATA_5V','LED_DIN',145,273,angle=90,sheet='io')
    part('D2','LED:WS2812B-2020','WS2812B-2020','Pico:WS2812B_2020_Compact',
         {1:None,2:'GND',3:'LED_DIN',4:'VBUS_USB'},198,278,sheet='io')
    passive('C25','1uF','VBUS_USB','GND',231,274,sheet='io',note='At RGB VDD')
    passive('C26','100nF','VBUS_USB','GND',264,274,sheet='io',note='At LV1T125 VCC')

    # Explicit power-source assertions: passive filters do not propagate ERC drive.
    for i,net in enumerate(['GND','VBUS_USB','VBUS_FUSED','+5V','V3A']):
        part('#FLG%02d'%i,'power:PWR_FLAG','PWR_FLAG','',{1:net},303+i*16,268,sheet='io')

    # Increase the IO sheet to A2 to keep the last row away from the title block.
    for sheet, filename in [('core','esp32-c6-pico.kicad_sch'),('io','power-io.kicad_sch')]:
        cache = [A('lib_symbols')]
        for original_id, sym in USED.items():
            s = copy.deepcopy(sym)
            s[1] = 'Pico_Design:'+original_id.replace(':','__')
            for unit in children(s, 'symbol'):
                unit[1] = original_id.replace(':','__') + '_' + '_'.join(unit[1].split('_')[-2:])
            cache.append(s)
        paper = '(paper "A3")' if sheet == 'core' else '(paper "User" 420 330)'
        doc = form(f'(kicad_sch (version 20260306) (generator "eeschema") (generator_version "10.0") '
                   f'(uuid "{SHEET_ID[sheet]}") {paper} '
                   '(title_block (title "ESP32-C6 PICO - prototype Rev A") (date "2026-09-06") '
                   '(rev "A") (company "KZL") (comment 1 "RF and thermal validation required before production")))')
        doc.append(cache)
        doc.extend(SHEETS[sheet])
        doc.append(form('(embedded_fonts no)'))
        if sheet == 'core':
            doc.append(form('(sheet_instances (path "/" (page "1")))'))
        data = dumps(doc)+'\n'
        # Preserve the original root file's CRLF format; newly authored text uses LF.
        with (ROOT/filename).open('w',encoding='utf-8',newline='\r\n' if sheet=='core' else '\n') as f:
            f.write(data)

    local = form('(kicad_symbol_lib (version 20251024) (generator "kicad_symbol_editor"))')
    for old_id,sym in USED.items():
        s=copy.deepcopy(sym)
        s[1]=old_id.replace(':','__')
        for unit in children(s, 'symbol'):
            unit[1] = s[1] + '_' + '_'.join(unit[1].split('_')[-2:])
        local.append(s)
    (ROOT/'libs/Pico_Design.kicad_sym').write_text(dumps(local)+'\n',encoding='utf-8',newline='\n')
    (ROOT/'design-spec.json').write_text(json.dumps(PARTS,indent=2,ensure_ascii=False)+'\n',encoding='utf-8',newline='\n')
    out=ROOT/'output'
    out.mkdir(exist_ok=True)
    with (out/'bom.csv').open('w',encoding='utf-8-sig',newline='') as f:
        writer=csv.writer(f,lineterminator='\n')
        writer.writerow(['Reference','Value','MPN','Footprint','Populate','Note'])
        for p in PARTS:
            writer.writerow([p['ref'],p['value'],p['mpn'],p['footprint'],'NO' if p['dnp'] else 'YES',p['note']])
    print(f'Generated {len(PARTS)} board components across two schematic sheets.')


if __name__ == '__main__':
    build()

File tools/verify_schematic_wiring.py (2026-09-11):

"""Audit visible pin-to-peripheral wires without resolving net or power labels."""
from pathlib import Path
import math
from kicad_sexpr import read,child,children,prop

def audit(root):
    doc=read(Path(root)/'esp32-c6-pico.kicad_sch')
    libraries={s[1]:s for s in children(child(doc,'lib_symbols'),'symbol')}
    pins={};wires=[];points=set();parents={}
    def point(q):return tuple(round(float(v),4) for v in q)
    for instance in children(doc,'symbol'):
        ref=prop(instance,'Reference')
        if ref.startswith('#'):continue
        x,y,angle=map(float,child(instance,'at')[1:]);a=math.radians(angle)
        for unit in children(libraries[child(instance,'lib_id')[1]],'symbol'):
            for pin in children(unit,'pin'):
                px,py=map(float,child(pin,'at')[1:3])
                q=point((x+px*math.cos(a)-py*math.sin(a),y-px*math.sin(a)-py*math.cos(a)))
                pins[(ref,child(pin,'number')[1])]=q;points.add(q)
    for wire in children(doc,'wire'):
        a,b=[point(q[1:]) for q in children(child(wire,'pts'),'xy')]
        wires.append((a,b));points.update((a,b))
    usb_labels={net:[point(child(label,'at')[1:3]) for label in children(doc,'global_label')
                     if label[1]==net] for net in ['USB_D-','USB_D+']}
    for locations in usb_labels.values():points.update(locations)
    def find(q):
        parents.setdefault(q,q)
        if parents[q]!=q:parents[q]=find(parents[q])
        return parents[q]
    def join(a,b):parents[find(a)]=find(b)
    def lies(q,a,b):
        return min(a[0],b[0])<=q[0]<=max(a[0],b[0]) and min(a[1],b[1])<=q[1]<=max(a[1],b[1]) and abs((q[0]-a[0])*(b[1]-a[1])-(q[1]-a[1])*(b[0]-a[0]))<1e-7
    for a,b in wires:
        for q in points:
            if lies(q,a,b):join(a,q)
    required=[('C19','1','U1','2'),('C20','1','U1','3'),('C11','1','U1','2'),('L2','2','U1','2'),
              ('C12','1','U1','5'),('C13','1','U1','28'),('C14','1','U1','37'),('C15','1','U1','40'),
              ('R7','2','U1','4'),('C21','1','U1','4'),('SW1','1','U1','4'),
              ('R8','2','U1','15'),('SW2','1','U1','15'),('R9','2','U1','14'),
              ('C7','1','U1','23'),('U3','8','U1','23'),('C6','1','U3','8'),
              ('Y1','1','R18','2'),('Y1','3','U1','38'),('R18','1','U1','39'),('C5','1','U1','38'),
              ('R14','1','U1','29'),('D6','1','U1','14'),('R19','2','D6','2'),('R15','1','D6','2'),('R15','2','D2','3'),
              ('C3','1','U1','1'),('L1','1','U1','1')]
    for ref,mcu,flash in [('R17','20','1'),('R1','21','2'),('R2','22','3'),('R3','24','7'),('R4','25','6'),('R5','26','5')]:
        required.extend([(ref,'1','U1',mcu),(ref,'2','U3',flash)])
    checks=[dict(from_pin=f'{r}.{n}',to_pin=f'{s}.{m}',connected=(r,n) in pins and (s,m) in pins and find(pins[r,n])==find(pins[s,m])) for r,n,s,m in required]
    # A cross-sheet label is an endpoint; matching label names never add graph edges.
    for pin,net in [('18','USB_D-'),('19','USB_D+')]:
        checks.append(dict(from_pin=f'U1.{pin}',to_label=net,
            connected=('U1',pin) in pins and bool(usb_labels[net])
            and all(find(pins['U1',pin])==find(q) for q in usb_labels[net])))
    return dict(all_passed=all(c['connected'] for c in checks),connections=checks,
                method='Visible wires only; labels and power-symbol aliases are not electrical edges')

if __name__=='__main__':
    import json
    result=audit(Path(__file__).resolve().parents[1]);print(json.dumps(result,indent=2))
    raise SystemExit(0 if result['all_passed'] else 1)

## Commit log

2026-09-07 Initial ESP32-C6 Pico KiCad design
    [bom.csv, esp32-c6-pico.kicad_pcb, esp32-c6-pico.kicad_sch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]
2026-09-08 Refine ESP32-C6 Pico layout and project handoff
    Update the 20.5 x 32 mm layout, antenna and crystal placement, USB routing, via clearances, and silkscreen logos. Keep RF passives at 0201 and use 0402 for all other resistors and capacitors. Draw ESP32-C6 peripherals directly from U1 pins.
    Refresh BOM, placement files, previews, validation reports, and project guidance. Exclude KiCad backup folders, autosaves, and local state on Windows and Linux.
    Validation: ERC, DRC, and unconnected counts are zero; all 45 QA checks passed. Verify final file hashes and backup exclusions before commit.
    [bom.csv, esp32-c6-pico.kicad_pcb, esp32-c6-pico.kicad_sch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]
2026-09-09 Compact board to 20 x 29 mm and synchronize schematic fields
    Move the antenna to the right with a direct feed, place the Codex logo on
    the left, and retain 3.8 mm of antenna clearance. Preserve the header
    pattern while trimming 0.25 mm from each side of the board.
    Fix the 65 schematic field mismatches and refresh placement, BOM,
    previews, dimensional checks, and layout documentation.
    Validation: ERC, unconnected items, and schematic parity report zero
    issues. The two pre-existing C12/C21 hole-clearance violations remain;
    independent QA was skipped at the user's request.
    [bom.csv, esp32-c6-pico.kicad_pcb, esp32-c6-pico.kicad_sch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]
2026-09-09 Fix crystal series resistor to match ESP32-C6 module reference
    Replace L4 with R18 = 0R and the standard 0402 resistor symbol and footprint.
    Synchronize BOM, placement, previews, design notes and reference checks.
    Include the official DevKitC reference and the peripheral circuit review.
    Validation: ERC, schematic parity and unconnected counts are zero.
    DRC retains two existing hole-clearance violations; QA passes 43 of 48
    checks with the five existing failure conditions documented.
    [bom.csv, esp32-c6-pico.kicad_pcb, esp32-c6-pico.kicad_sch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]
2026-09-09 optimize crystal rounting
    [esp32-c6-pico.kicad_pcb]
2026-09-09 Move headers inward by 0.3 mm and refresh layout outputs
    Keep the 20 x 29 mm outline and move J2/J3 inward to a 17.50 mm
    column spacing. Adjust local routing and labels, then refresh placement,
    previews, geometry checks and fabrication notes. Preserve the subsequent
    back-logo move and corrected drawing dimensions.
    Validation: DRC, unconnected items and schematic parity all zero.
    Independent QA passes 44/49 checks; the five failures predate this change.
    Verified the input baseline and kept schematic, rules and RF/XTAL/USB
    routing unchanged.
    [esp32-c6-pico.kicad_pcb, placement.csv, via-in-pad.csv]
2026-09-09 optimize USB vbus routing and other
    [esp32-c6-pico.kicad_pcb]
2026-09-09 Restore SOIC-8 flash, shrink USB diode and remove input fuse
    Use W25Q32JVSNIQ in a 150 mil SOIC-8 footprint and BAT760-7 in
    SOD-323. Remove F1 and connect USB VBUS directly to the blocking
    diode. Preserve the board outline and RF, crystal and USB data routing.
    Synchronize schematics, BOM, placement, previews, fabrication notes and
    independent checks. ERC, DRC, unconnected items and schematic parity
    are all zero. QA passes 45 of 51 checks, retaining six pre-existing failures.
    [bom.csv, esp32-c6-pico.kicad_pcb, esp32-c6-pico.kicad_sch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]
2026-09-09 move L2 into B.Cu and optimize routing
    [esp32-c6-pico.kicad_pcb, placement.csv]
2026-09-11 Complete first PCB revision
    [bom.csv, esp32-c6-pico.kicad_pcb, esp32-c6-pico.kicad_sch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]
